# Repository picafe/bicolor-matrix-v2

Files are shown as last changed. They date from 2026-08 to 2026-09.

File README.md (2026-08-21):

# Bicolour Matrix

A 32x8 bicolor LED matrix module composed of 4 8x8 matrices based on the Holtek HT16K33A I2C LED driver. V1 paired it with a stacked adapter (RP2040 Zero + DS3231 module); V2 redesigns the matrix routing and puts an ESP32-C3, RTC, and environment sensors on a half-length adapter board behind the display.

V1 assembled clock showing the time

*V1 running as a clock*

## Inspiration

Inspired by the common 32x8 red LED matrix modules that use the MAX7219 IC, I wanted to make my own module but with more colours and functionality, while keeping the same asthetic.

I found [these](https://www.aliexpress.com/item/1005007029570407.html) modules while browsing Aliexpress and thought they could look be a cool alternative, costing ~$15 for 10 modules. With the red and light green variant, you can have red, a light green, and orange all in one module. As far as I'm aware, there aren't RGB modules in a similar form factor, although you can take generic WS2818 8x8 matricies and 3D print a diffuser for them, although the footprint is much bigger. This project was also partially inspired by [bitluni's LED magnet tiles](https://www.youtube.com/watch?v=L2J_eNgjxio) which I found really cool.

Unlike the single colour matricies with 16 pins, these had 24. I found [this](https://www.adafruit.com/product/902) Adafruit module and followed a similar schematic with the Holtek HT16K33A I2C LED driver.

For V2 I revisited the HT16K33A datasheet and realized any ROW/COL pin can map to any matrix row/column, thus routing got a lot simpler than matching Adafruit's pinout exactly.

## Structure

| Board | Role |
| --- | --- |
| **bicolour-matrix** | 32×8 display: 4× HT16K33A + 4× 8×8 bicolour matrices |
| **adapter-board-r2** | ESP32-C3-WROOM-02, CH340X USB-UART, YSN8900 RTC + CR2032, STCC4 (default CO₂; optional SCD41), SHT4x, BMP580, LIS2DW12 |
| **button-board-r2** *(optional / WIP)* | OLED + light sensor + touch pads |

The adapter is half the length of the matrix board and mates with a pin header between the middle modules so that the stack stays stable without a case.

The button board is a separate interface that is connected to the adapter board with a 7-pin JST SH connector. This is meant to be customized and built by the user themselves, although I've included a sample design with an OLED, light sensor, and 2x touch pads you can start from. What you include and how you integrate it is up to you and how you want to design an enclosure.

## Pictures

### Assembled (V1)

V1 boards laid out - adapter, button board, matrix

V1 side / stack view

### V2 

#### 3D

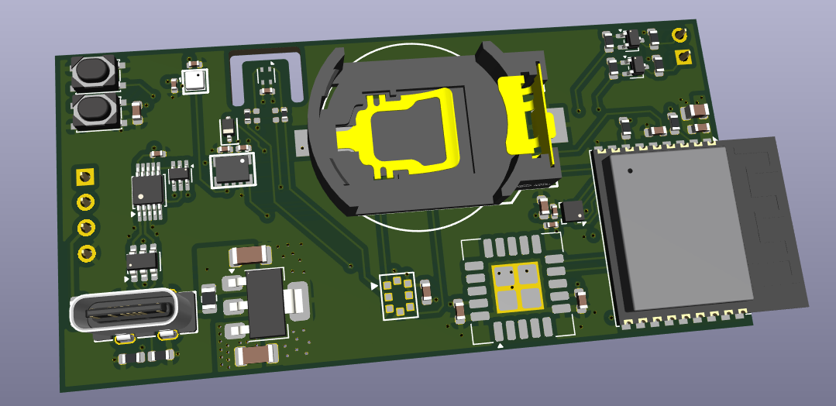
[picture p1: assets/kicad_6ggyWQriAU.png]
Adapter board R2 3D view


*Adapter board R2 (3D)*

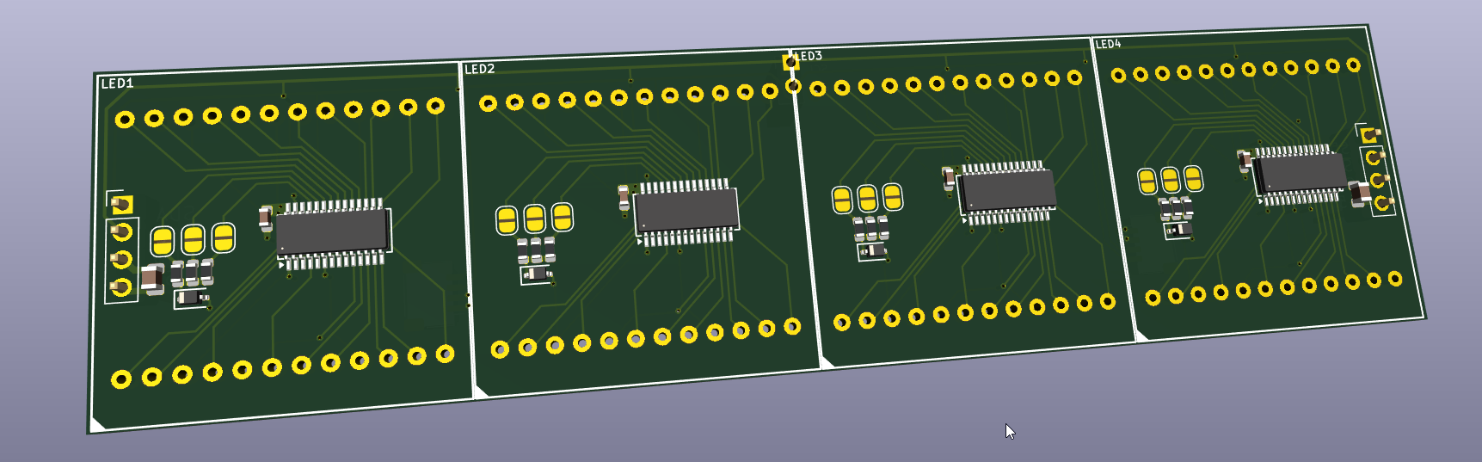
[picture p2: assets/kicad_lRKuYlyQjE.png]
Matrix board R2 3D view


*Matrix board R2 (3D)*

#### Schematics

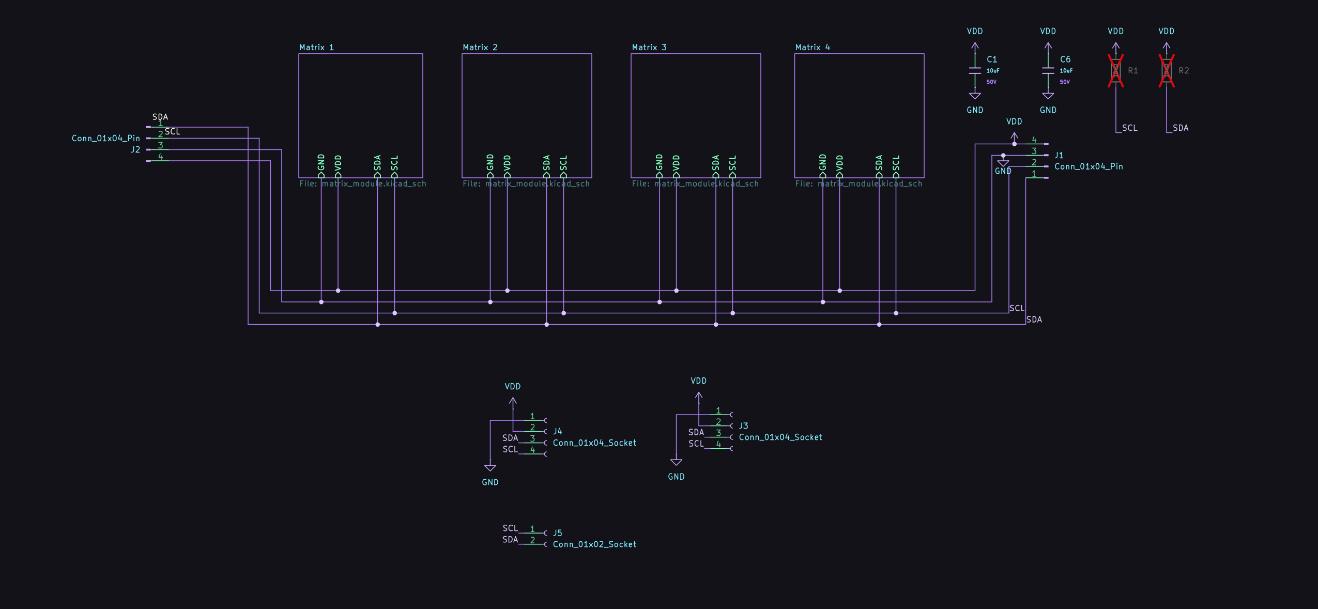
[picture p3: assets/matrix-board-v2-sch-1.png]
Matrix board schematic

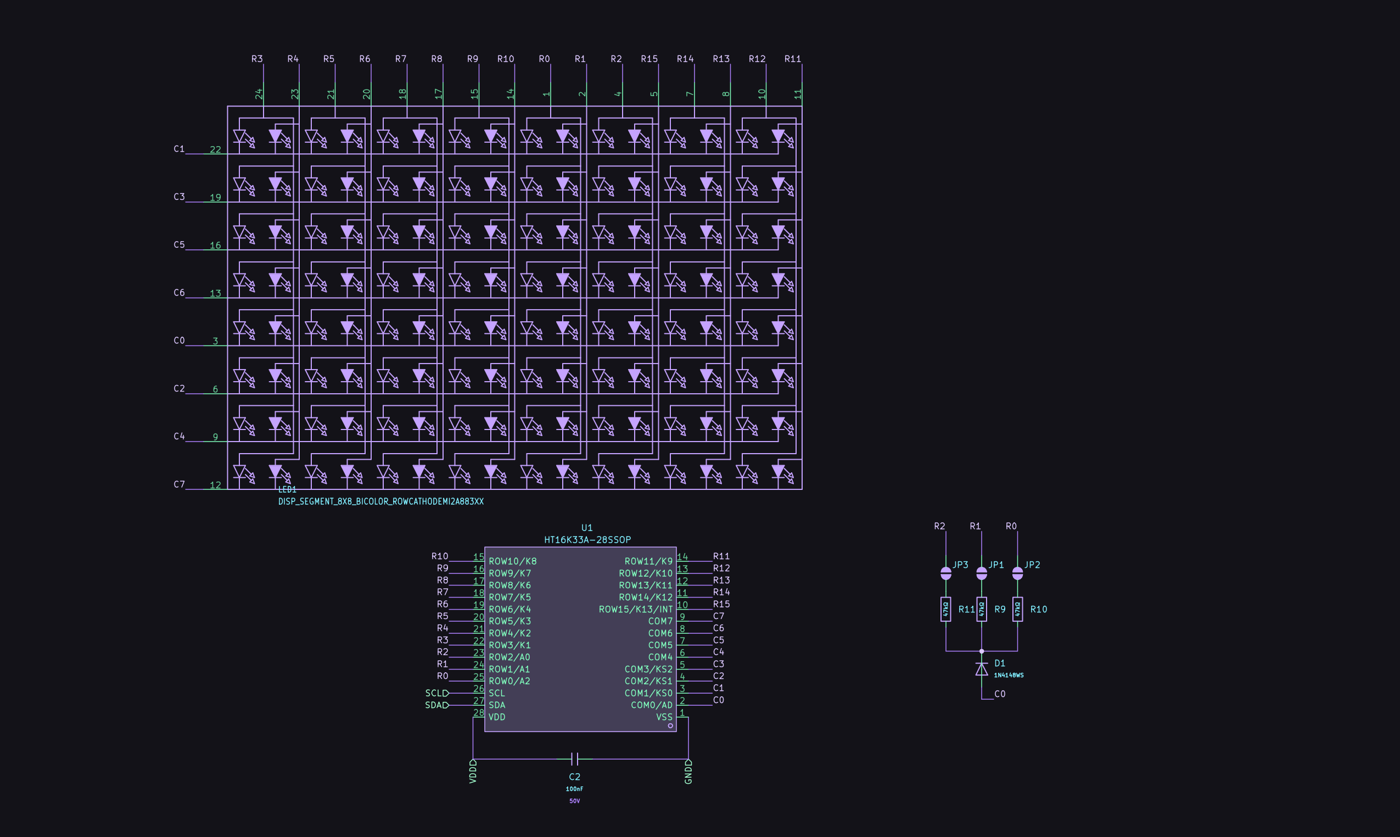
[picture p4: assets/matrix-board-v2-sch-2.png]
Matrix board module schematic


*Matrix board schematic*

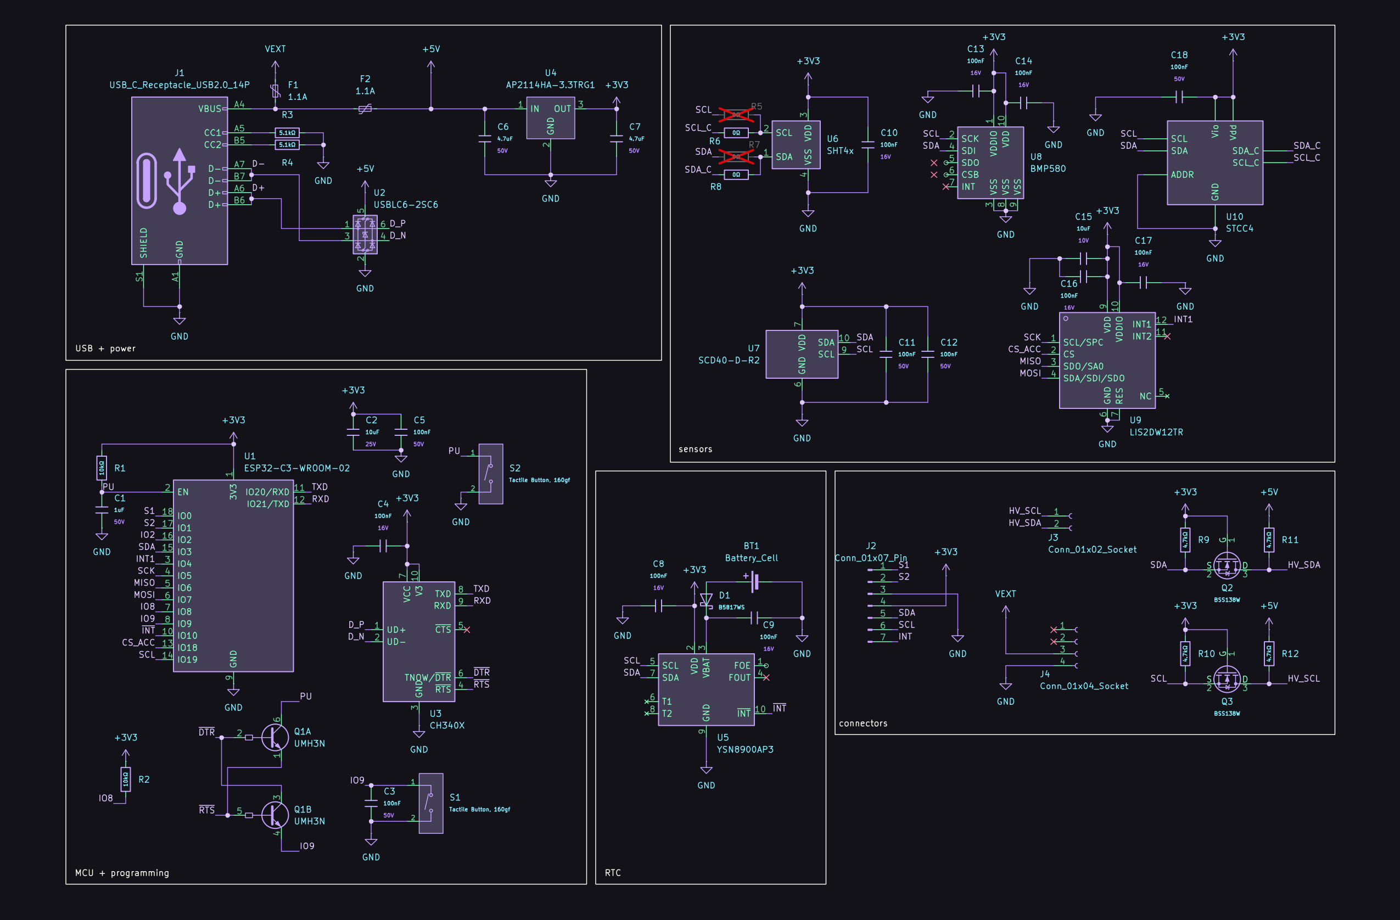
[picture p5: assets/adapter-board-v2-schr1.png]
Adapter board schematic

*Adapter board R2 schematic*

#### PCB

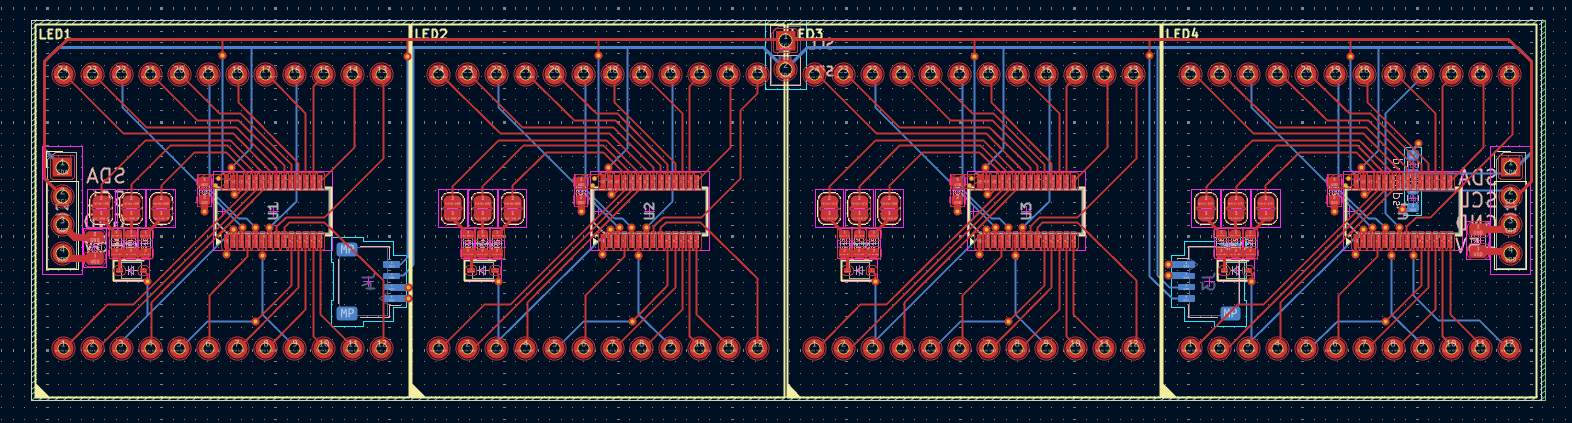
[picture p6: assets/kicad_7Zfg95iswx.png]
Matrix board R2 PCB layout


*Matrix board PCB (four HT16K33A modules)*

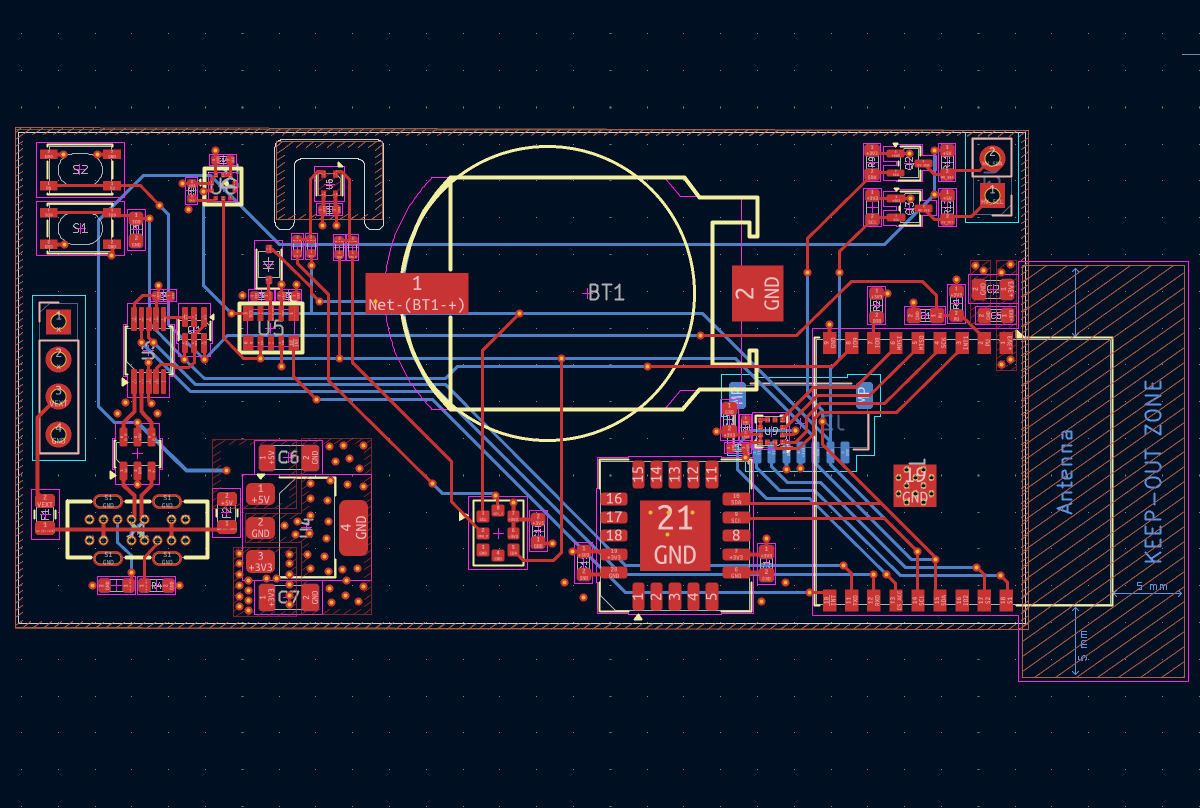
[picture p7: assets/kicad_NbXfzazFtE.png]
Adapter board R2 PCB layout


*Adapter board R2 PCB*

## Bill of materials

Prices are estimated from LCSC single-board quantities and AliExpress for the LED matrices.

### Matrix board (`bicolour-matrix`)

| Designator | Value | Footprint | Qty | LCSC | Unit cost (est.) | Line total (est.) |
| --- | --- | --- | --- | --- | --- | --- |
| C1, C6 | 10 µF | 0805 | 2 | C440198 | $0.02 | $0.04 |
| C2, C3, C4, C5 | 100 nF | 0603 | 4 | C14663 | $0.01 | $0.04 |
| D1, D2, D3, D4 | 1N4148WS | SOD-323 | 4 | C2128 | $0.01 | $0.04 |
| J1, J2 | 1×04 pin header | Through hole | 2 | — | $0.05 | $0.10 |
| J3, J4 | JST SH 1×04 (Qwiic-style) | SMD | 2 | — | $0.15 | $0.30 |
| J5 | 1×02 socket | Through hole | 1 | — | $0.05 | $0.05 |
| LED1, LED2, LED3, LED4 | 8×8 bicolour matrix | Module | 4 | AliExpress | $2.00 | $8.00 |
| R3, R4, R5, R9, R10, R11, R13, R14, R15, R18, R19, R20 | 47 kΩ | 0603 | 12 | C25819 | $0.002 | $0.02 |
| U1, U2, U3, U4 | HT16K33A | SSOP-28 | 4 | C5444738 | $0.54 | $2.16 |
| | | | | **Total (matrix, components only)** | | **~$10.75** |

### Adapter board (`adapter-board-r2`)

Default build uses the STCC4 for CO₂. An SCD41 (U7) can be fitted instead if R6/R8 are left open and the unpopulated R5/R7 0 Ω jumpers are fitted (routes the SHT4x onto the main I²C bus instead of the STCC4 compensation bus).

| Designator | Value | Footprint | Qty | LCSC | Unit cost (est.) | Line total (est.) |
| --- | --- | --- | --- | --- | --- | --- |
| BT1 | CR2032 holder | SMD | 1 | C7498149 | $0.15 | $0.15 |
| C1 | 1 µF | 0603 | 1 | C15849 | $0.01 | $0.01 |
| C3, C5, C11, C12, C18 | 100 nF | 0603 | 5 | C14663 | $0.01 | $0.05 |
| C4, C8, C9, C10, C13, C14, C16, C17 | 100 nF | 0402 | 8 | C1525 | $0.005 | $0.04 |
| C15 | 10 µF | 0603 | 1 | C19702 | $0.02 | $0.02 |
| C2 | 10 µF | 0805 | 1 | C15850 | $0.03 | $0.03 |
| C6, C7 | 4.7 µF | 1206 | 2 | C29823 | $0.03 | $0.06 |
| D1 | B5817WS | SOD-323 | 1 | C7420329 | $0.05 | $0.05 |
| F1, F2 | 1.1 A fuse | 0805 | 2 | — | $0.05 | $0.10 |
| J1 | USB-C receptacle 14P | Through hole | 1 | C3151746 | $0.30 | $0.30 |
| J2 | JST SH 1×07 | SMD | 1 | — | $0.25 | $0.25 |
| J3 | 1×02 socket | Through hole | 1 | — | $0.05 | $0.05 |
| J4 | 1×04 socket | Through hole | 1 | — | $0.08 | $0.08 |
| Q1 | UMH3N | SOT-363 | 1 | — | $0.08 | $0.08 |
| Q2, Q3 | BSS138W | SOT-323 | 2 | C28646265 | $0.03 | $0.06 |
| R1, R2 | 10 kΩ | 0603 | 2 | C25804 | $0.002 | $0.004 |
| R3, R4 | 5.1 kΩ | 0603 | 2 | C23186 | $0.002 | $0.004 |
| R6, R8 | 0 Ω (STCC4 / SHT4x compensation) | 0402 | 2 | C17168 | $0.004 | $0.008 |
| R9, R10, R11, R12 | 4.7 kΩ | 0603 | 4 | C23162 | $0.002 | $0.008 |
| S1, S2 | Tactile button, 160 gf | PTS810 | 2 | C720477 | $0.10 | $0.20 |
| U1 | ESP32-C3-WROOM-02 | Module | 1 | C2934560 | $3.13 | $3.13 |
| U2 | USBLC6-2SC6 | SOT-23-6 | 1 | C7519 | $0.18 | $0.18 |
| U3 | CH340X | MSOP-10 | 1 | C3035748 | $0.67 | $0.67 |
| U4 | AP2114HA-3.3TRG1 | SOT-223 | 1 | C460314 | $0.25 | $0.25 |
| U5 | YSN8900AP3 | SMD3225-10P | 1 | C54780223 | $1.46 | $1.46 |
| U6 | SHT4x | DFN-4 | 1 | — | $1.20 | $1.20 |
| U8 | BMP580 | LGA-10 | 1 | C22391138 | $0.96 | $0.96 |
| U9 | LIS2DW12TR | LGA-12 | 1 | C189624 | $1.26 | $1.26 |
| U10 | STCC4 | LGA | 1 | C49191471 | $10.06 | $10.06 |
| | | | | **Total (adapter, default build)** | | **~$20.73** |

Optional (not in default total): U7 SCD41 (~$18, C3659421) with R5/R7 fitted and R6/R8 open; leave U10 unpopulated.

**Combined components (matrix + adapter, default): ~$31.48**  
*(PCBs: ~$30 matrix + ~$12 adapter at JLCPCB)*

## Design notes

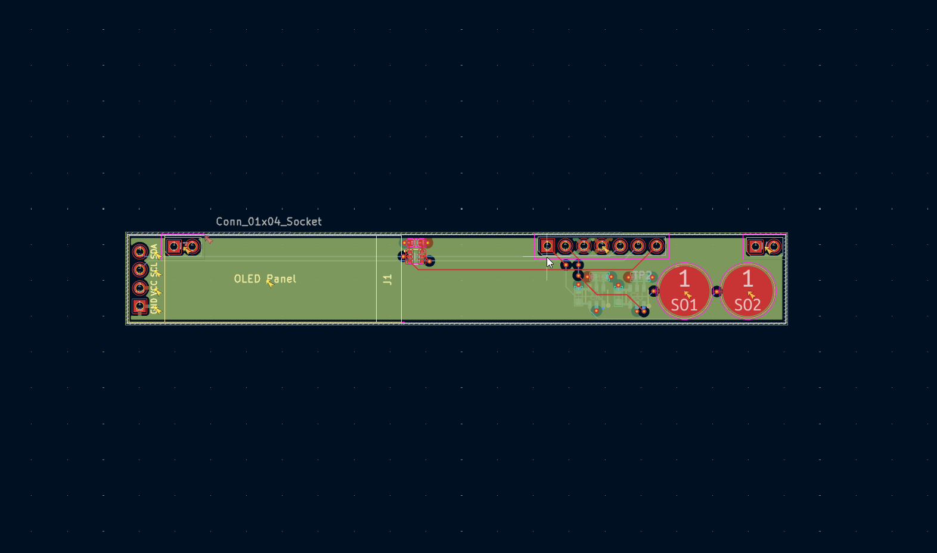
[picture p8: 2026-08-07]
assets/kicad_tJa7MA0nMc.png

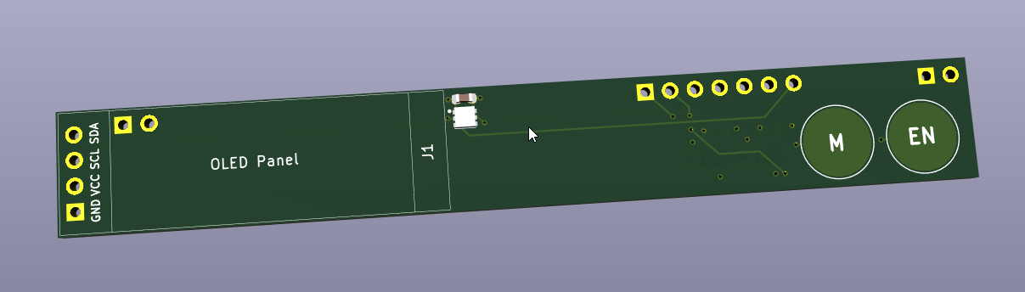
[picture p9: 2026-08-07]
assets/kicad_IC0JWIbxsM.png

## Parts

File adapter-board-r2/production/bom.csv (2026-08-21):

Designator | Footprint | Quantity | Value | LCSC Part #
BT1 | BAT-SMD_BS-CR2032-8 | 1 | Battery_Cell | C7498149
C1 | C_0603 | 1 | 1uF | C15849
C10, C13, C14, C16, C17, C4, C8, C9 | C_0402 | 8 | 100nF | C1525
C11, C12, C18, C3, C5 | C_0603 | 5 | 100nF | C14663
C15 | C_0603 | 1 | 10uF | C19702
C2 | C_0805 | 1 | 10uF | C15850
C6, C7 | C_1206 | 2 | 4.7uF | C29823
D1 | D_SOD-323 | 1 | B5817WS | C7420329
F1, F2 | 0805 | 2 | 1.1A
J1 | USB-C-TH_SHOUHAN_TYPE-C-14PLC-H10.0 | 1 | USB_C_Receptacle_USB2.0_14P | C3151746
J2 | JST_SH_SM07B-SRSS-TB_1x07-1MP_P1.00mm_Horizontal | 1 | Conn_01x07_Pin
J3 | PinSocket_1x02_P2.54mm_Vertical | 1 | Conn_01x02_Socket
J4 | PinSocket_1x04_P2.54mm_Vertical | 1 | Conn_01x04_Socket
Q1 | SOT-363_SC-70-6 | 1 | UMH3N
Q2, Q3 | SOT-323_SC-70 | 2 | BSS138W | C28646265
R1, R2 | R_0603 | 2 | 10kΩ | C25804
R10, R11, R12, R9 | R_0603 | 4 | 4.7kΩ | C23162
R3, R4 | R_0603 | 2 | 5.1kΩ | C23186
R6, R8 | R_0402 | 2 | 0Ω | C17168
S1, S2 | SW_SPST_PTS810 | 2 | Tactile Button, 160gf | C720477
U1 | ESP32-C3-WROOM-02 | 1 | ESP32-C3-WROOM-02
U10 | STCC4 | 1 | STCC4 | C49191471
U2 | SOT-23-6 | 1 | USBLC6-2SC6
U3 | MSOP-10_3x3mm_P0.5mm | 1 | CH340X
U4 | SOT-223 | 1 | AP2114HA-3.3TRG1 | C460314
U5 | OSC-SMD_10P-L3.2-W2.5-BL_RX8130CE | 1 | YSN8900AP3 | C54780223
U6 | Sensirion_DFN-4_1.5x1.5mm_P0.8mm_SHT4x_NoCentralPad | 1 | SHT4x
U7 | Sensirion_SCD4x-1EP_10.1x10.1mm_P1.25mm_EP4.8x4.8mm | 1 | SCD40-D-R2
U8 | LGA-10_L2.0-W2.0-P0.50-TL_BMP580 | 1 | BMP580 | C22391138
U9 | LGA-12_2x2mm_P0.5mm | 1 | LIS2DW12TR | C189624

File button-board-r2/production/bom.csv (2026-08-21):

Designator | Footprint | Quantity | Value | LCSC Part #
C1, C3, C5 | C_0603 | 3 | 100nF | C14663
C2, C4 | C_0603 | 2 | 22pF | C1653
J1 | SSD1306-0.91-OLED-4pin-128x32 | 1 | Conn_01x04_Socket
J2 | JST_SH_SM07B-SRSS-TB_1x07-1MP_P1.00mm_Horizontal | 1 | Conn_01x07_Pin
TP1, TP2 | TestPoint_Pad_D4.0mm | 2 | TestPoint
U1 | SENSORS-SMD_VEML6030 | 1 | VEML6030 | C132182
U2, U3 | SOT-23-6_L2.9-W1.6-P0.95-LS2.9-BL | 2 | TTP223-BA6-TD | C42422127

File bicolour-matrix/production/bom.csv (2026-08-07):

Designator | Footprint | Quantity | Value | LCSC Part #
C1, C6 | C_0805 | 2 | 10uF | C440198
C2, C3, C4, C5 | C_0603 | 4 | 100nF | C14663
D1, D2, D3, D4 | D_SOD-323 | 4 | 1N4148WS | C2128
J1, J2 | PinHeader_1x04_P2.54mm_Vertical | 2 | Conn_01x04_Pin
J3, J4 | JST_SH_SM04B-SRSS-TB_1x04-1MP_P1.00mm_Horizontal | 2 | Conn_01x04_Socket
J5 | PinSocket_1x02_P2.54mm_Vertical | 1 | Conn_01x02_Socket
LED1, LED2, LED3, LED4 | SEGMENT_BICOL_BL-M12A883XX | 4 | DISP_SEGMENT_8X8_BICOLOR_ROWCATHODEMI2A883XX
R10, R11, R13, R14, R15, R18, R19, R20, R3, R4, R5, R9 | R_0603 | 12 | 47kΩ | C25819
U1, U2, U3, U4 | SSOP-28_3.9x9.9mm_P0.635mm | 4 | HT16K33A-28SSOP | C5444738

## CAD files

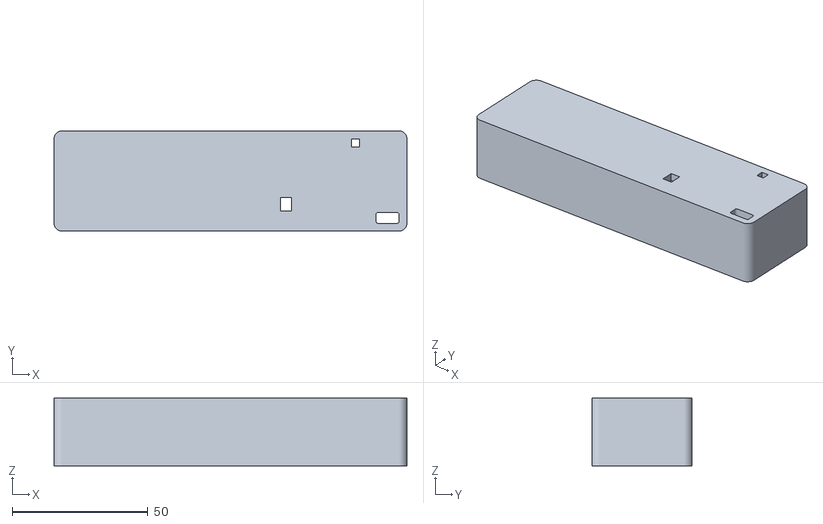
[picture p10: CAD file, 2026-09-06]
cad/Enclosure-r2.stl
130.0 x 37.0 x 25.0

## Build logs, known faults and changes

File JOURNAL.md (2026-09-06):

Total time spent: 21 hours

# June 15, 2025: Coming back for R2 - freer pinout & QWIIC

Note: I built R1 over the span of a few months, modifying a few things as I went. I didn't record many details, but the finished results are pictured in the README.md.

I wanted to come back to this project as I realized a few days earlier while revisiting the HT16K33A datasheet that I didn't realize before (since I wasn't too proficient in reading datasheets; in fact I doubt I even read it in detail back then). In my original design, I decided to follow the exact connections Adafruit used in their module, not realizing that any ROW pin on the HT16K33A can be connected to any row on the display matrix and such with COL pins too. This meant that I could simplify the routing a lot. I also wanted to include QWIIC connectors to make it easy to chain 2 modules together (the max that can be connected on the same bus, since I2C addr select is 3 bits/jumpers).

I tested the setup on a breadboard and asked Claude to make a modification to the library implementation for the new pinout, which worked fine. I also wanted to change the adapter board to include an actual microcontroller itself rather than a soldered module. The current solution is not too neat/ideal. I'm thinking maybe a NRF52840/NRF52833 module.

I started (and finished) work on the matrix module itself pretty easily. It took a bit to remember how to use the replicate layout plugin again and route the rest manually.

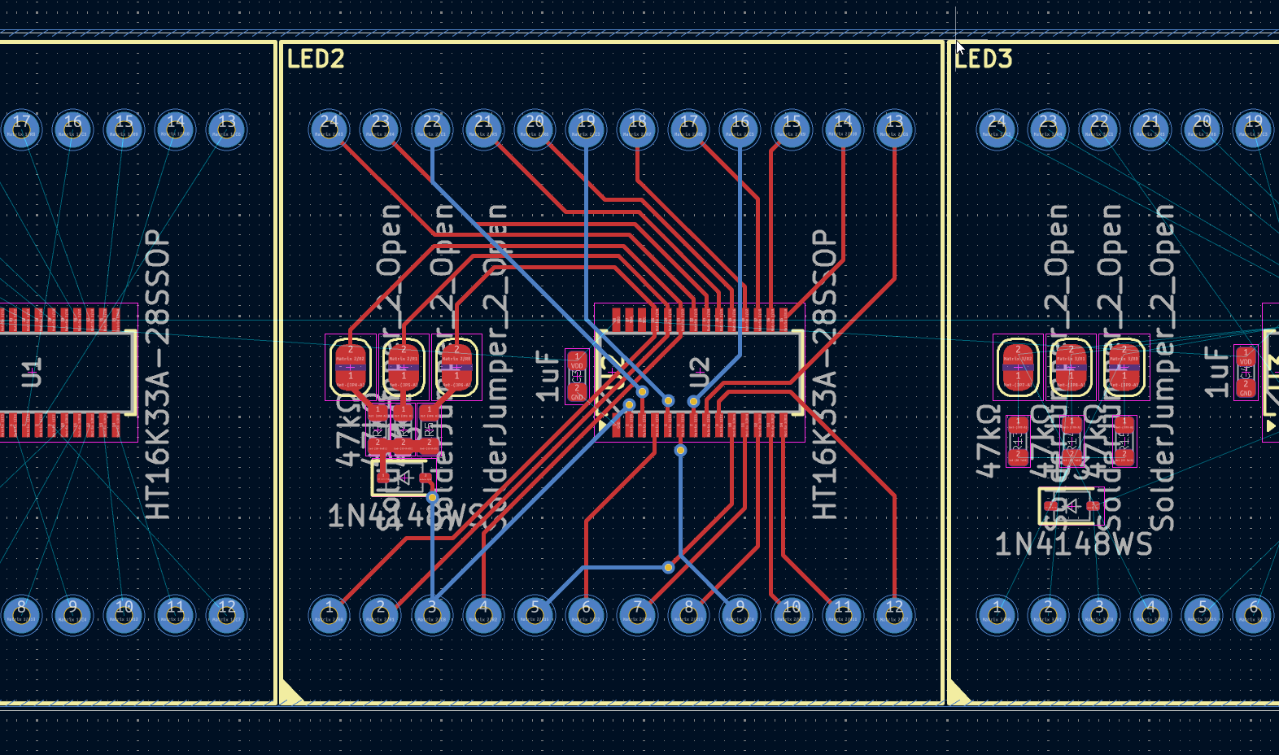
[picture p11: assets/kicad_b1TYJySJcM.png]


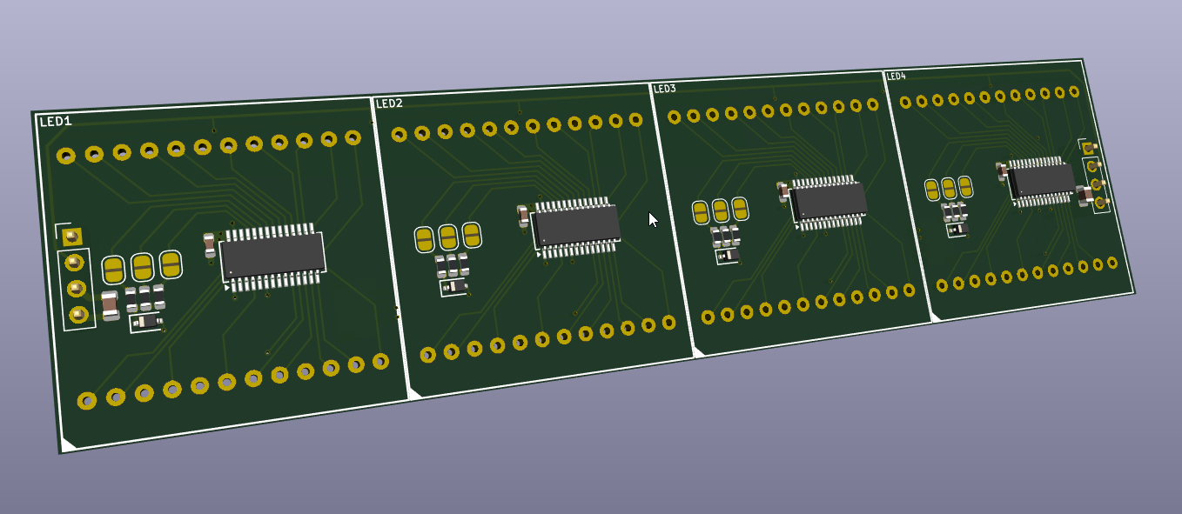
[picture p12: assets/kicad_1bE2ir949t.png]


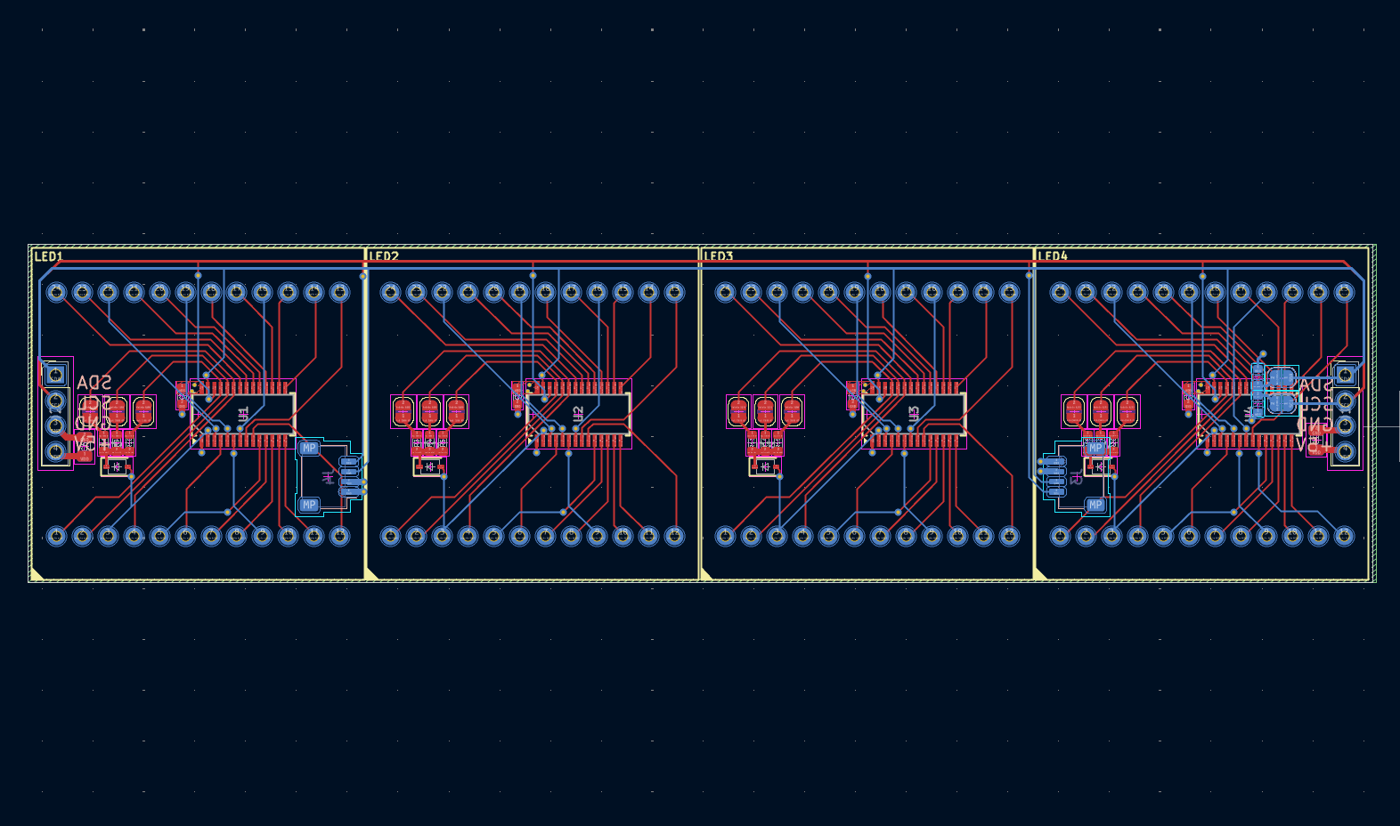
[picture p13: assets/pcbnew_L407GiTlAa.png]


**Total time spent: 3 hours**

# July 9, 2026: Started adapter board - switched to ESP32-C3

I have been a bit busy and procrastinating taking on the main task of making the adapter board. But I have finally started working on it. I decided to go with the ESP32-C3 WROOM module since it's small, has enough GPIO and is fairly cheap. The main reason I switched from what was initially planned (despite actually importing the symbol and starting the schematic) was that I wanted to make the programming/setup easy through something like a web dashboard which I would make a PWA. Would be much simpler than using Zephyr or Arduino IDE with Nordic MCU. ESP ecosystem w/ Arduino also has more overall support. It is also slightly cheaper than the NRF52840/NRF52833 module from Ebyte I planned on using.

I spent a while reading over the ESP32-C3 WROOM datasheet, integration guide, placement requirements and took a lot at the schematic + PCB for the devboard. I also read up on the boot and reset behaviour, and figured it would just be easier to use a CH340 instead of onboard USB for programming, since it supports autoreset.

Since board space isn't an issue, I went for CH340N. It took me a while to find an appropriate LDO for the system, since my system probably would have current peaks of 500mA+. I wanted to use a SOT-23 package since it's easy to route and after scrolling past the pages of 1117-style regulators, I found the AP2114HA, which is suitable. After drafting a quick schematic, I called it for the day. But before that, I cleaned up the schematic a bit.

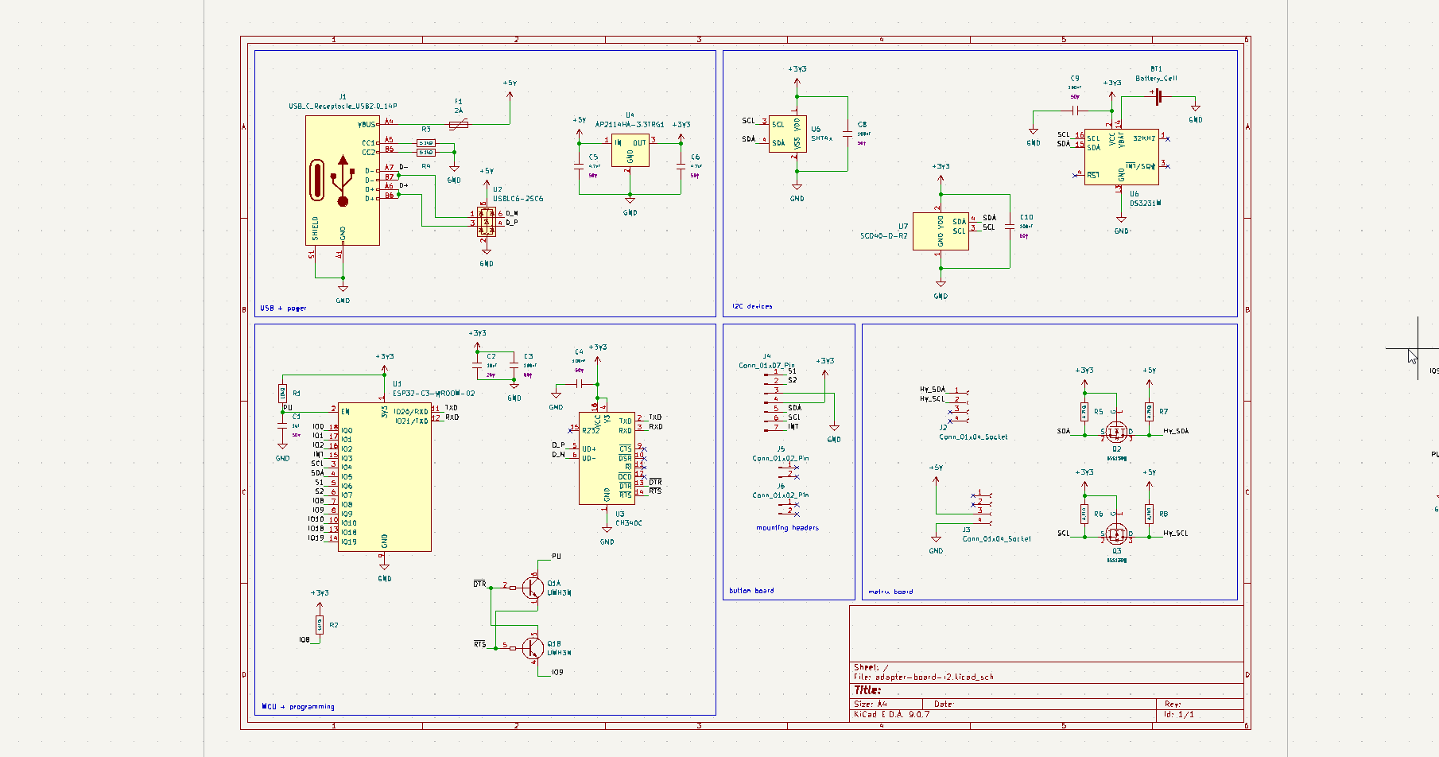
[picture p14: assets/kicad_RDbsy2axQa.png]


**Total time spent: 3.5 hours**

# July 10, 2026: Routed the adapter board - then sticker shock at JLC

I finally locked in an routed the majority of the adapter board, although I still had quite a bit of empty space on the board; it felt like a lot of space being wasted. The routing was fairly simple and took me in total about 2.5 hours becuase of the low component density. The main things were connecting the D+/D- pairs together on the horizontal USB connector since they crossed each other in a somewhat X shape and I needed 5V to pass through the middle of the connector. Eventually, I just resorted to using the inner GND layer to connect them as there wasn't a filled region in that area due to keepout.

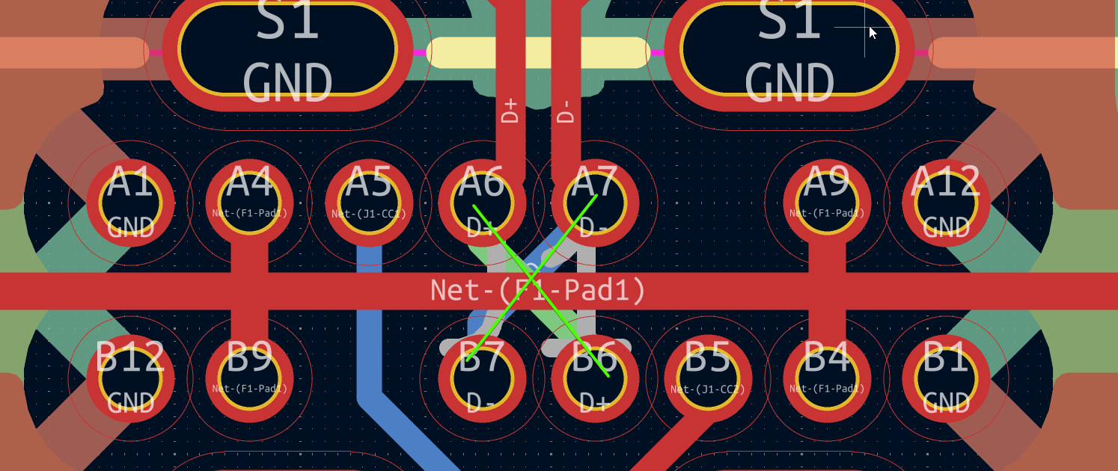
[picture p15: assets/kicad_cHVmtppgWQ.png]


After I while I was done routing:

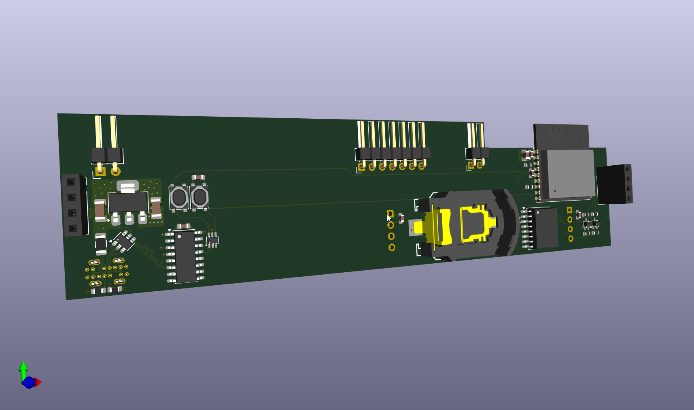
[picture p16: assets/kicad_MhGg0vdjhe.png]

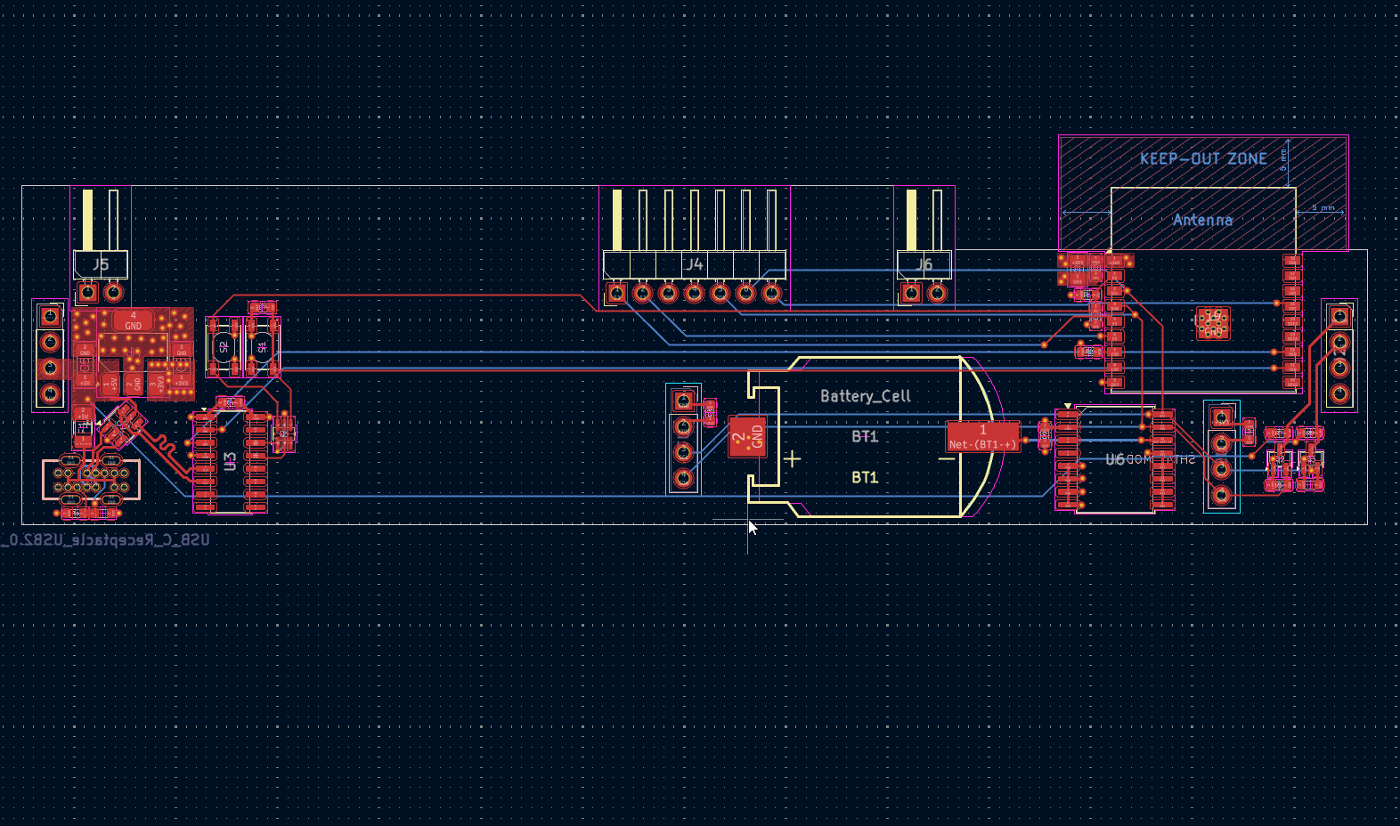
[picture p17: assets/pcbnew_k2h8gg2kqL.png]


However, when I was done routing, I put the PCB into JLC to see how much it would cost, since I've never ordered a 4 layer board above 100x100mm. It turned out to be quite expensive...

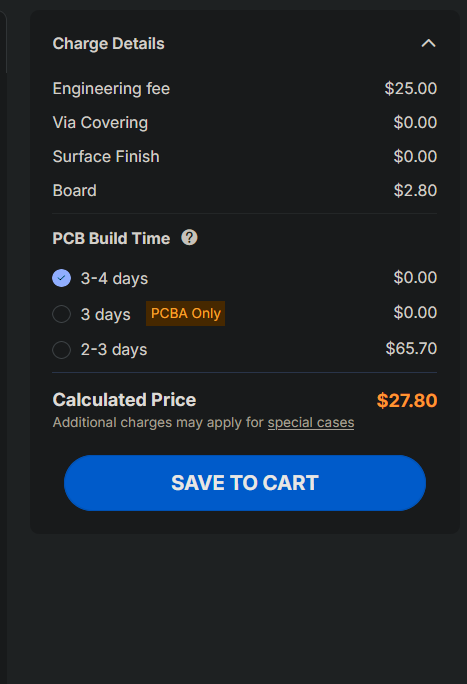
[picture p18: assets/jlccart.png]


I figured this would be acceptable for the matrix board since essentially all of the space was utilized, however since the adapter board is pretty bare, I figured it would likely be better to split this into 2 boards potentially, or make the board smaller and attach it to the matrix board with an additional pin header in the middle between one of the modules.

First I tried to see what it would look like to split the board into 2, with a pin header in the middle between the two modules. Even with this setup, the board would be pretty empty and there would be quite a bit of space wasted.

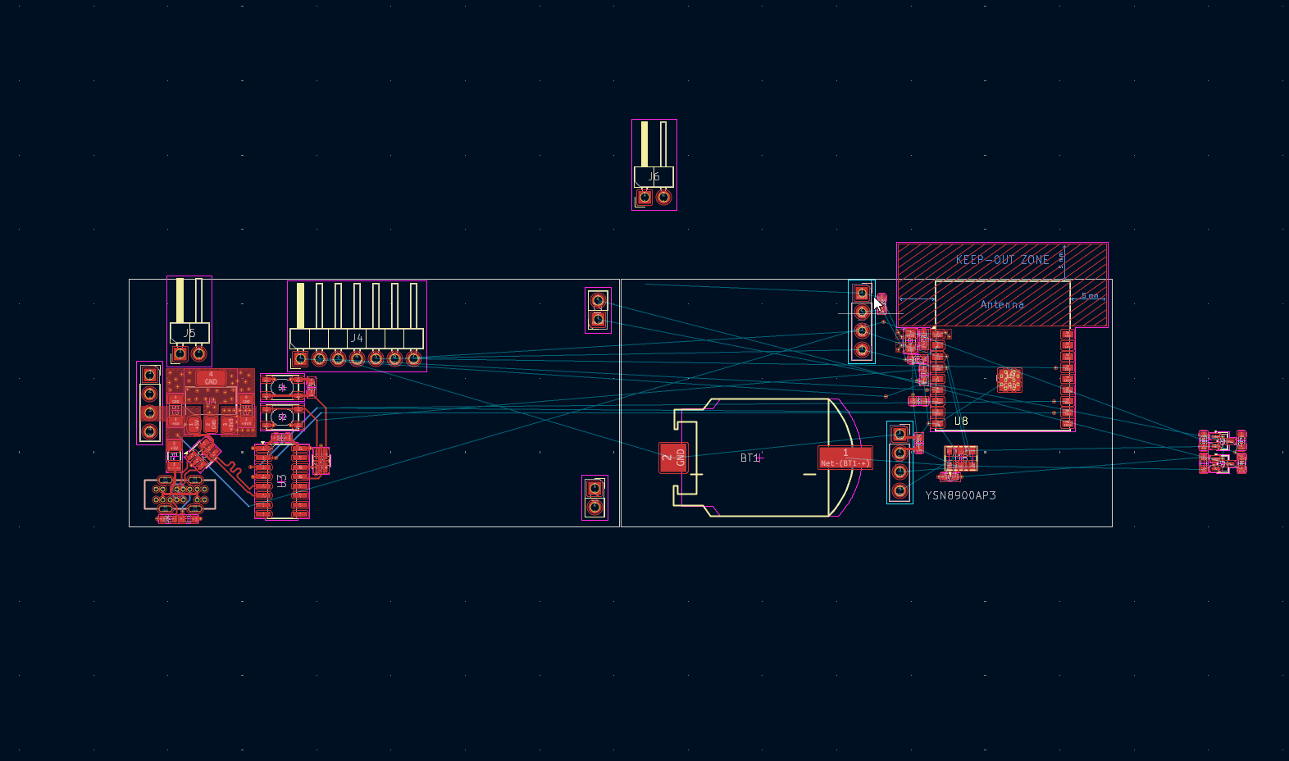
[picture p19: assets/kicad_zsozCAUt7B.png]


The distance betweenm the first and 3rd module is essentially 100mm, so this is essentially the maximum distance that could be supported by a single board.



I thought initially this would be a good idea, since it would mean more space for routing and maximizing the PCB per cost that I pay for, but when I tried the rough layout, it was pretty hard to fit something in exactly 100mm without having the pin header holes on the matrix board being in a weird position or without having the pin header keepout be off the edge of the adapter board:

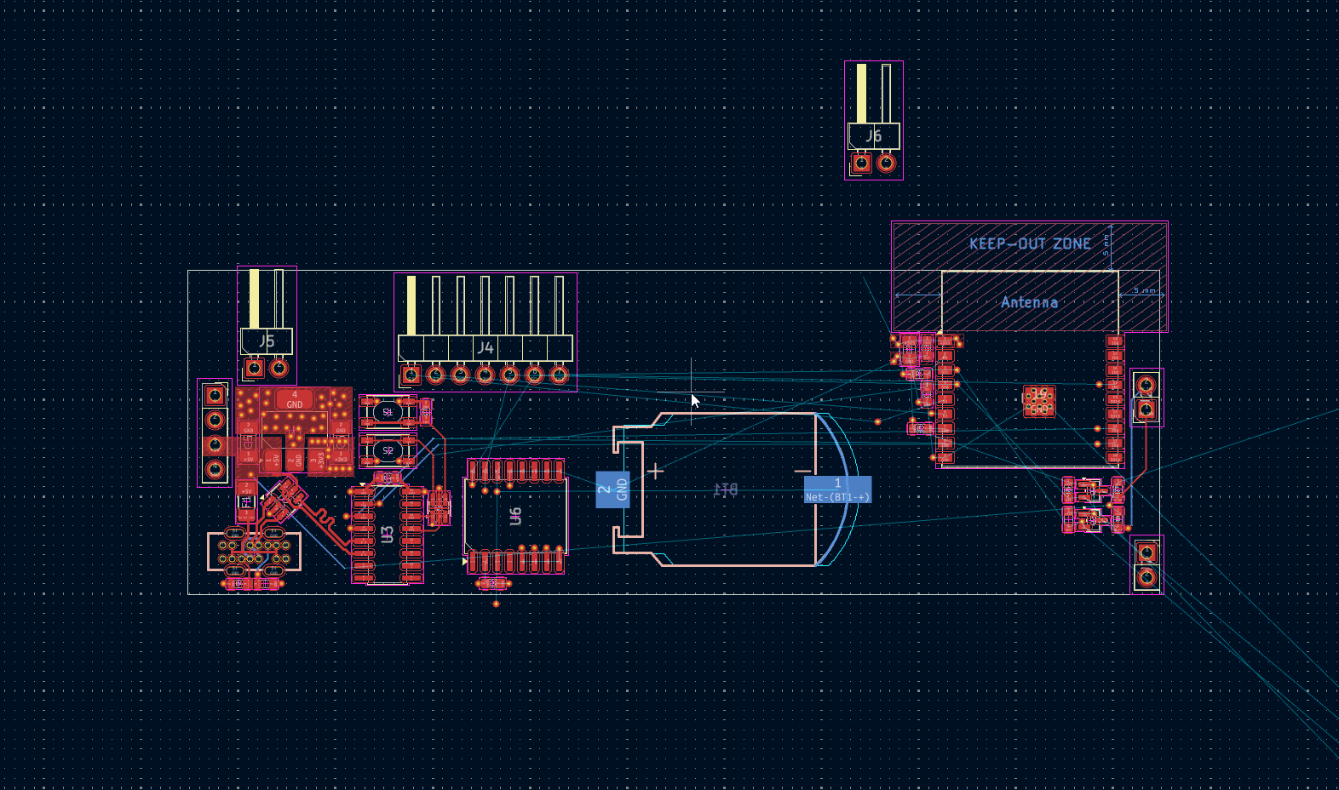
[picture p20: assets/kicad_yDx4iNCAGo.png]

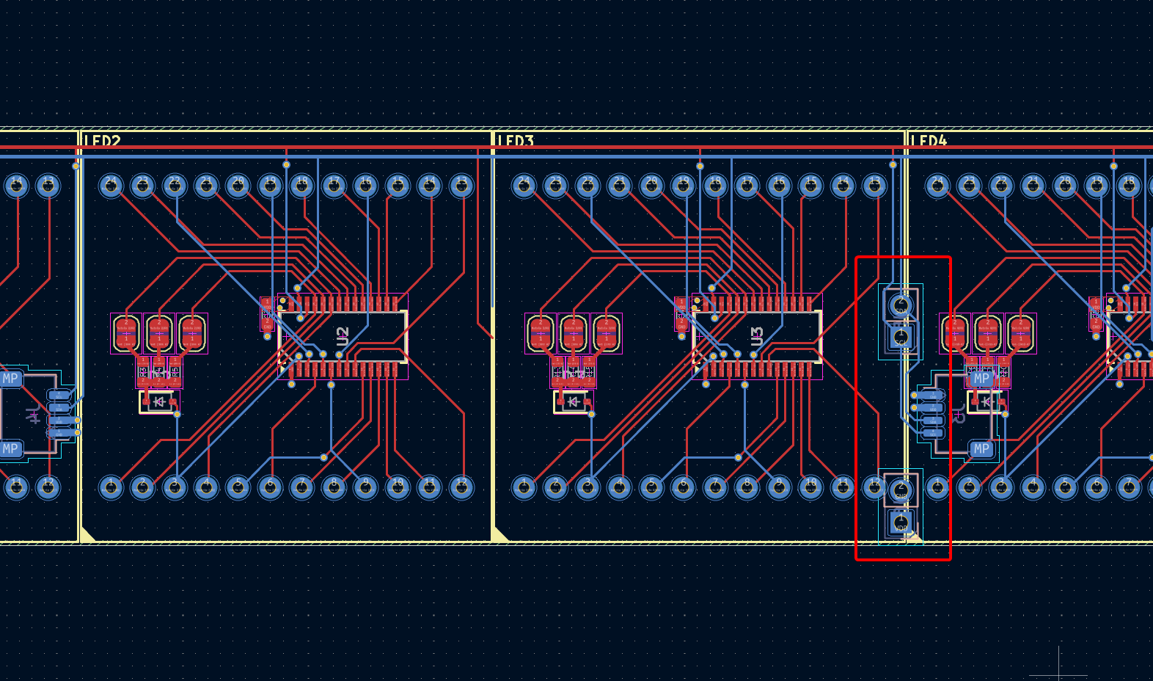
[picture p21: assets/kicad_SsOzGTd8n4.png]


Therefore, I settled on having the adapter board be half the length of the matrix module, and then having a pin header in the middle between the two modules.

**Total time spent: 6 hours**

# July 12, 2026: Rethinking layout - sensors go on the board

Before pretty much starting again on the adapter board, I decided to rethink a bit of the layout.
After reading the ESP32-C3 WROOM datasheet/recommand layout position documentation again, I decided on this new setup:

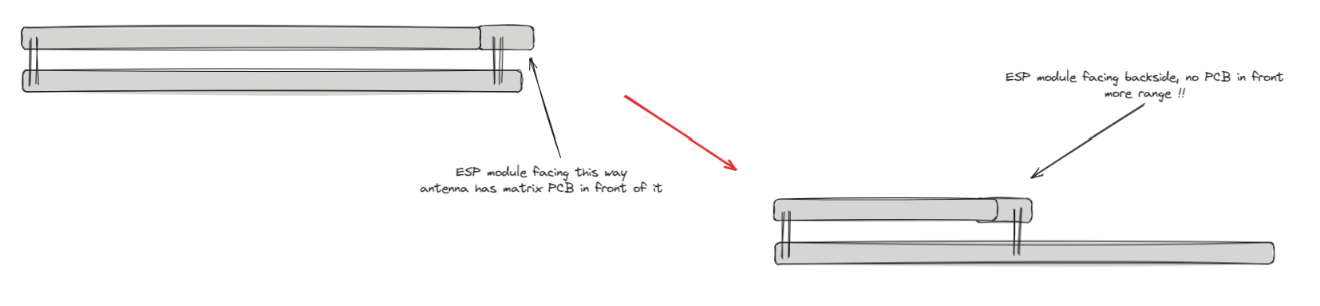
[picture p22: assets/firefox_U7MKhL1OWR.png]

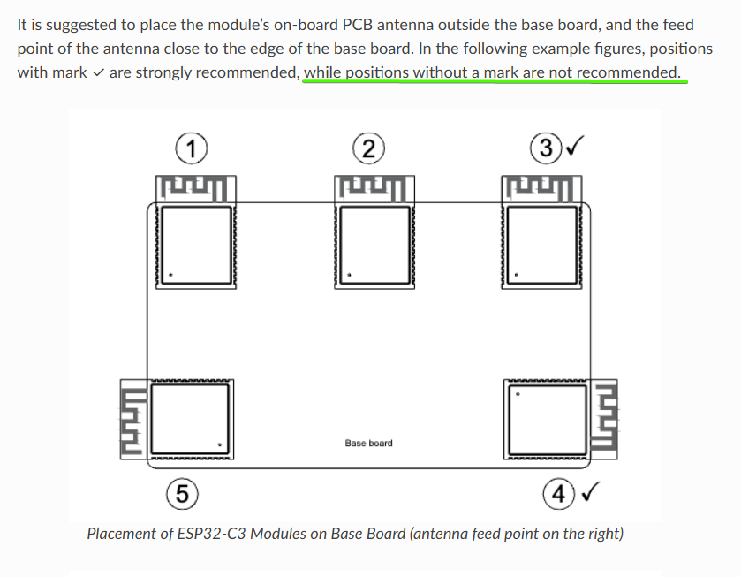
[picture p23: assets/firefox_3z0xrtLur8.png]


Since my previous layout had the module on the top side, I thought it might be better to place it sideways on the bottom now to accomadate more space for the pins to connect to the matrix board. Previously, I was also planning on using SCD41 and SHT41 breakout boards since they would be easy to solder, but I eventually decided to just use the actual sensors themselves and work on getting a better SMT setup, since I plan to assemble the board myself. Since everything was also going on the backside, I could include all the sensors on the same side since the SCD40 is about the same height as the vertical USB connector, which are both the tallest items on the board. I could also make an enclosure that follows one of the recommended layouts for general environment sensors to have them inside an isolated cavity in the case which is openly exposed, such that heat from components inside would not affect the sensors. Something like this:

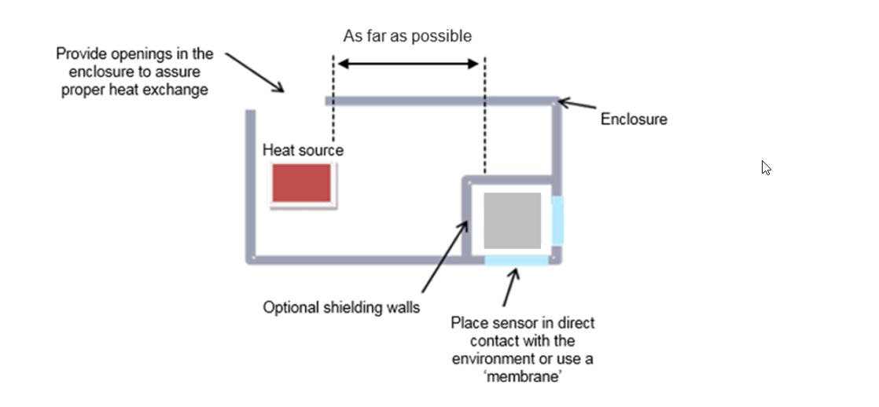
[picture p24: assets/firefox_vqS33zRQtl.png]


However, for now the design is intended to be caseless; which is one of the reasons why I spent so long trying to find a layout that works since pin headers need to be mounted on both sides of the board for it to be stable. I did previously work on a revision 2 of the button board which includes an 128x32 OLED, light sensor and 2 touch pads, it'll likely be redesigned later on so that I can figure out a better way to mount it to everything else with or without a case. I like the raw matrix/electronic look of the board, which is a reason why I want to keep this compatible without a case. This is still something I'm debating since environment sensors aren't too good with dust and such, but I think I'll probably make a version with a case later on.

After reading the SCD4x datasheet, I realized that the sensor has temperature and pressure compensation for CO2 concentration, so a better temperature/humidity sensor and a pressure sensor would be ideal for better accuracy. Out of the options on LCSC, I picked the ENS210 since it has the best specs based on what was available for a reasonable unit price. The SCD41 isn't available on LCSC, but I figured its big enough to order a module and desolder it, which would not be a good idea for the SHT41 since it's quite tiny. For pressure, I went with the BMP580; new and accurate. Although board heating shouldn't have much of an effect on the BMP580, I tried to keep it separate but not on an island by itself like I planned to do with the ENS210.

**Total time spent: 2 hours**

# July 16, 2026: Finished adapter board - sensors, RTC, accelerometer

After returning from a brief break, I decided to start working on the adapter board again. I decided to go with the same layout as I planned before (half the length of the matrix module), but with the new sensors and some other changes. One thing I did though was switch to the CH340X since it's smaller and I needed the extra space. Oh yeah, I also decided to go with a different RTC other than the DS3231 since it's fairly hard to source them nowadays and they're in a fairly big package. I went with a clone of the Epson RX8900SA from YXC (YSN8900AP3), which is a drop-in replacement from a trusted brand. It has an integrated TCXO in a SMD3225-10P package, making it easy to hand solder (with a reflow plate), small, accurate, and much cheaper than the DS3231.

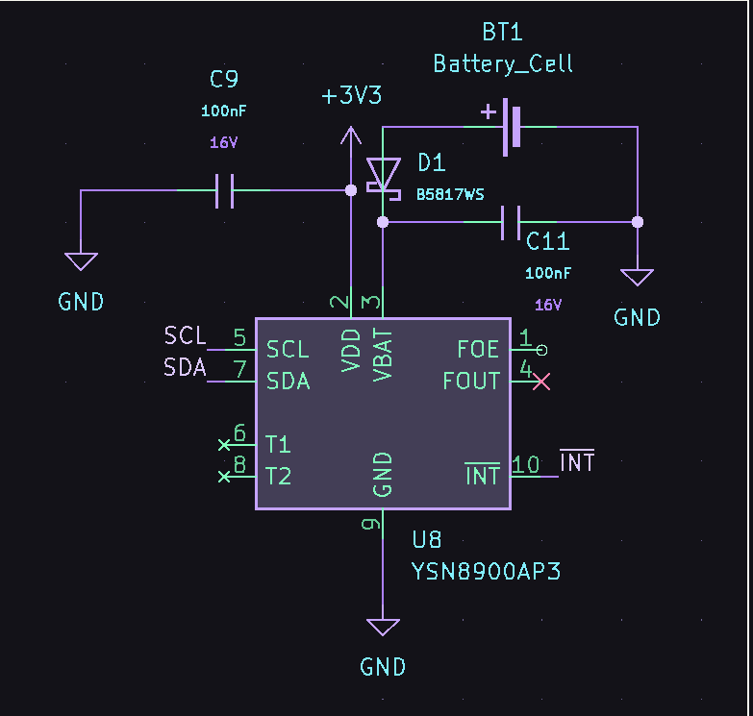
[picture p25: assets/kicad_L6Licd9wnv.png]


Routing in progress:

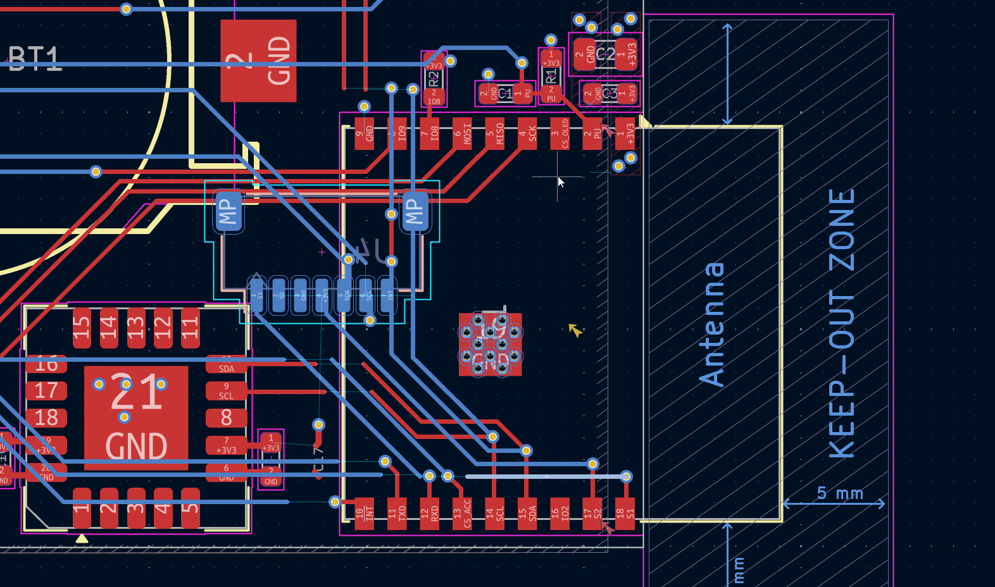
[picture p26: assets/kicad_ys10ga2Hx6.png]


Although it took quite a bit to route and get everything ironed out, finally managed to get something I considered acceptable. It was a bit hard to route the battery holder since I had to account for the battery radius (which was not included in the footprint), but overall it was not too bad.

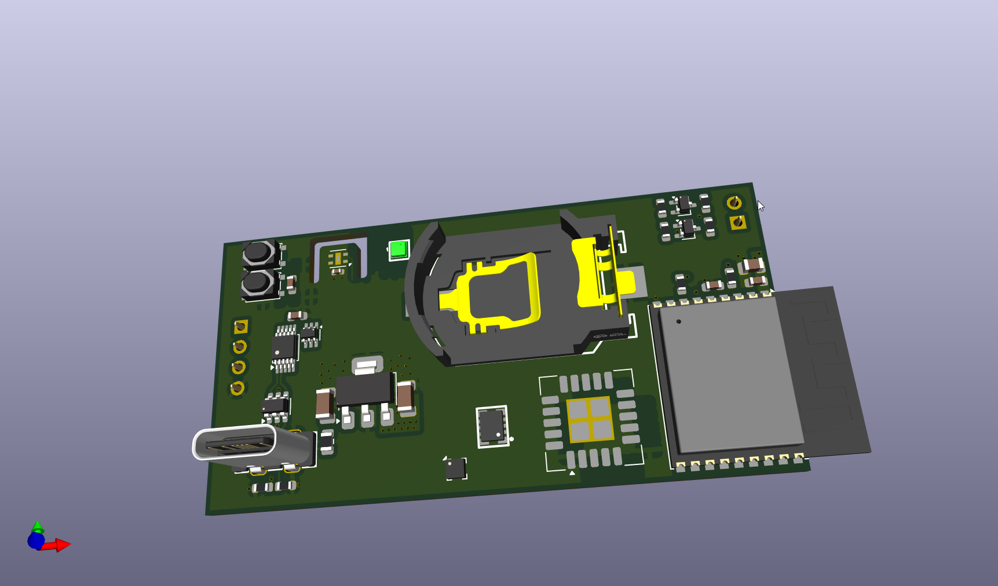
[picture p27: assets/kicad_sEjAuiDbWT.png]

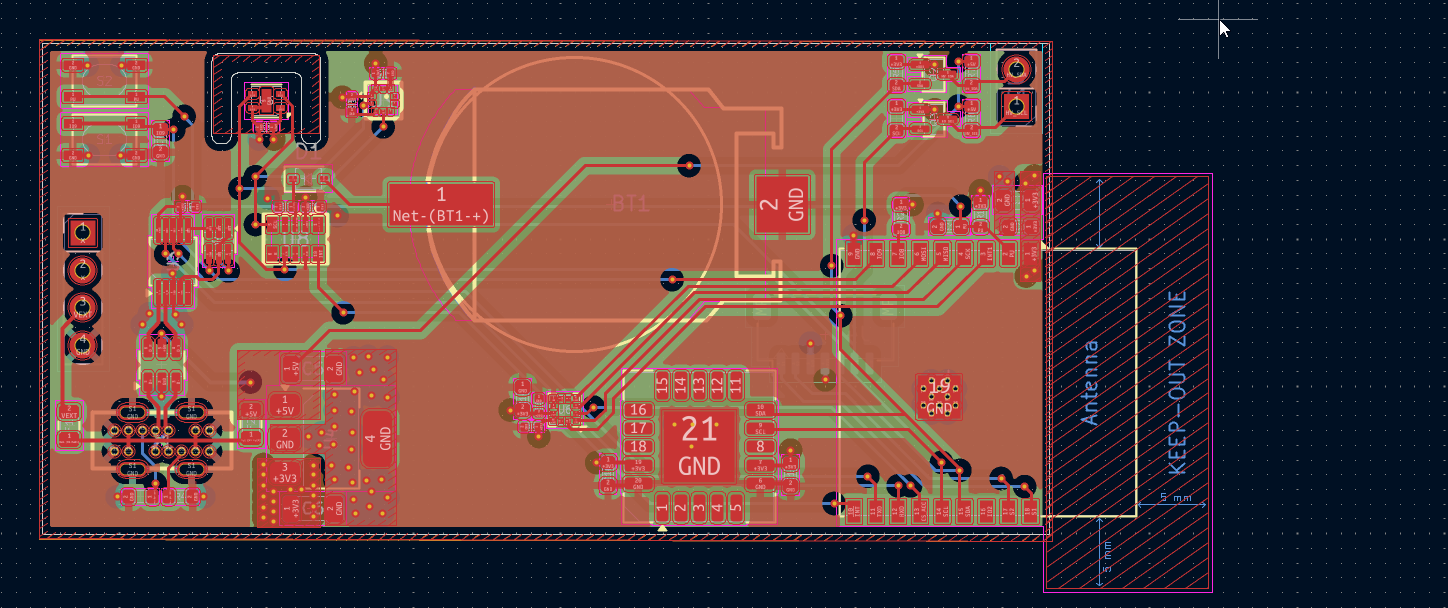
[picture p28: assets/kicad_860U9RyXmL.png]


Somewhere along the way, I also decided to add an accelerometer (LIS2DW12) to make this cable of some particle motion simulation or something like an hourglass feature, which would be pretty cool especially with 3 crisp colours on the matrix displays. After exporting the BOM and PCB to LCSC and JLC, everything came out to roughly $12 for the adapter board PCB, $35 for parts, and $30 for the matrix board PCB.

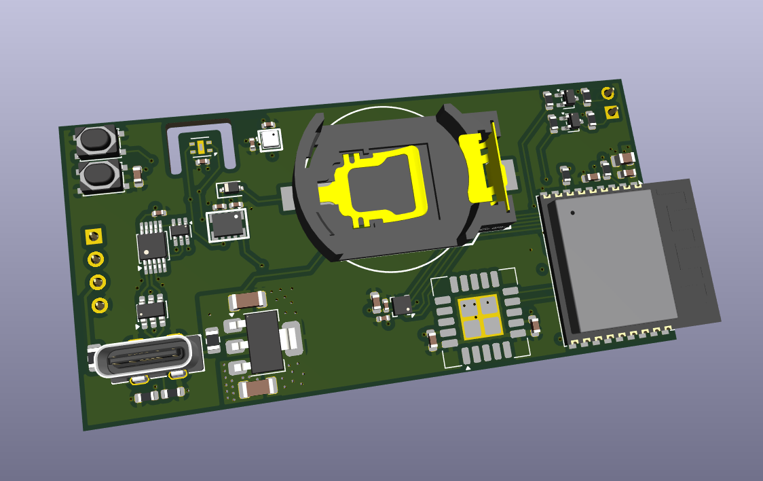
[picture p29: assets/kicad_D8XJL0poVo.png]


**Total time spent: 4 hours**

# August 18, 2026: Changed components - STCC4, SHT4x

After doing some cost comparisons, I decided to go with the STCC4 for CO₂ instead of the SCD41 while also keeping pads for the SCD41 in case. I also decided to go with the SHT4x for humidity and temperature instead of the ENS210, since it's supported by default with the STCC4 for compensation. I just added 0402 0 ohm jumpers to connect the SHT4x to the STCC4 compensation bus instead of the main I²C bus. I also had to re-route a lot of other components like the accelerometer and RTC to fit traces.

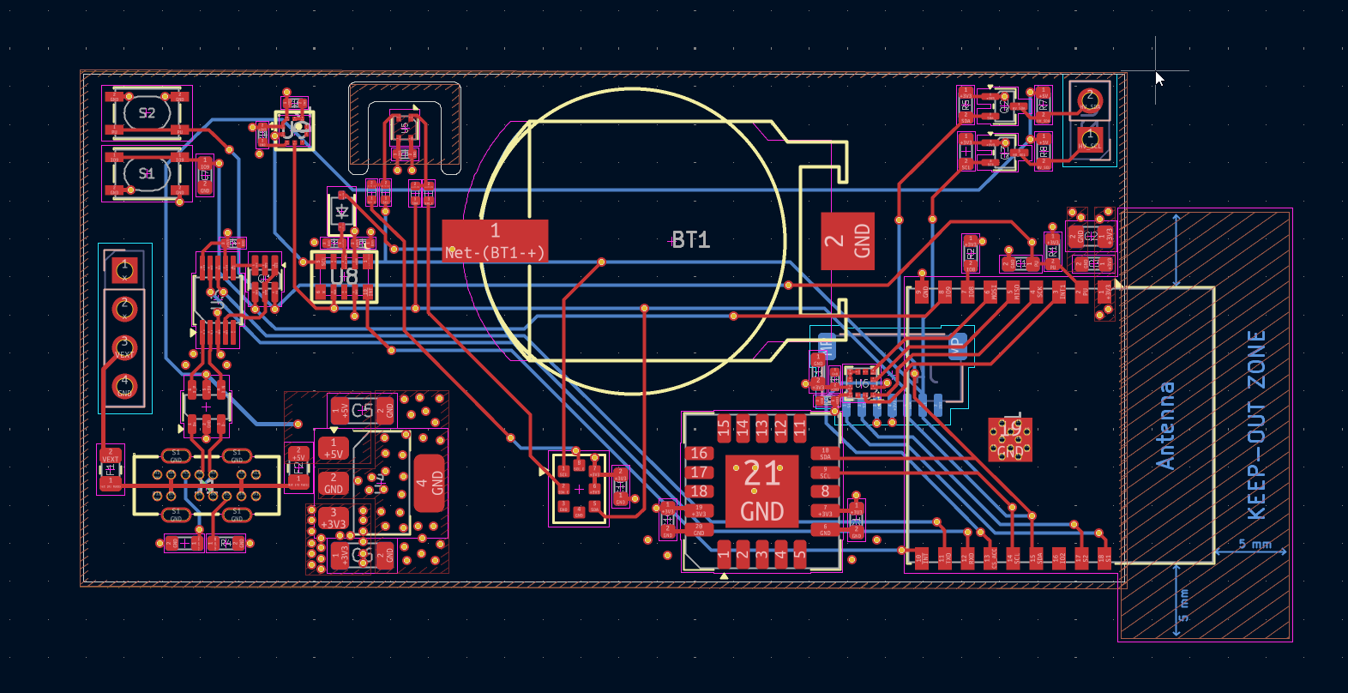
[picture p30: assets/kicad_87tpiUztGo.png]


**Total time spent: 1.5 hours**

# August 26, 2026: Routing and silkscreen changes

I made a few changes to the routing of the main adapter board, since I had some traces in weird places from before; since I had to move matricies to adjust alignment so a few traces were not perfectly straight. Since I have to get this via a green PCB, the misalignment would be noticeable. I also added some orph and heidi pcb art from hc stickers!! I also added silkscreen labels for everything.

**Total time spent: 1 hour**

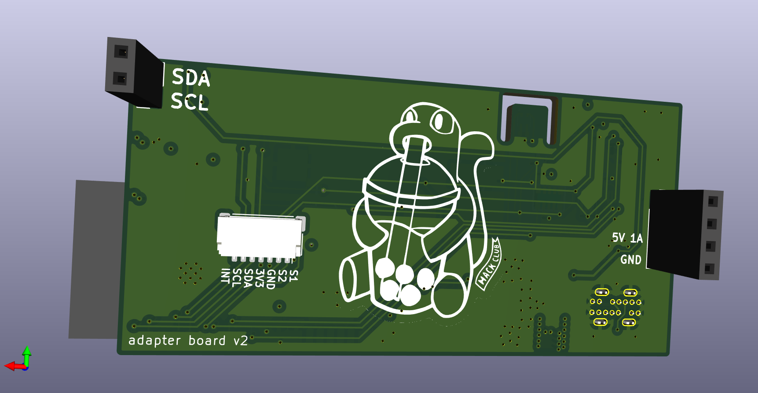
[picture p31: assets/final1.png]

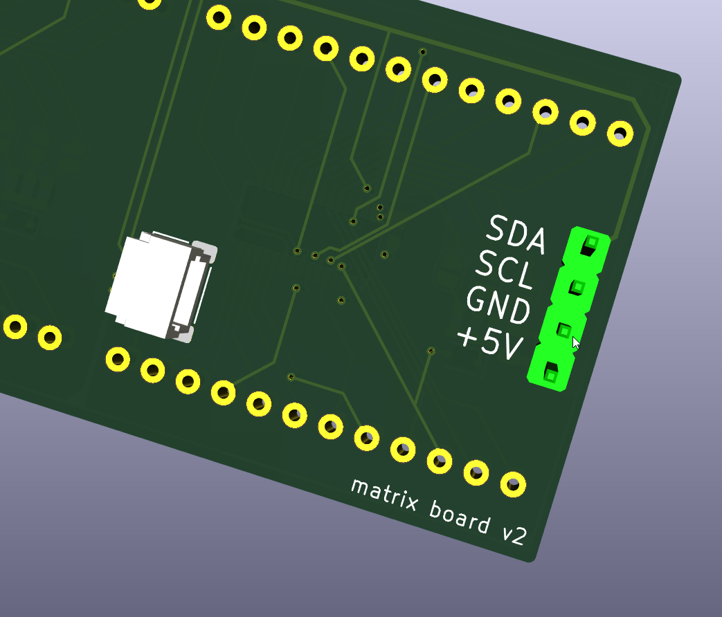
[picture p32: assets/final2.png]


# September 6, 2026: Simple enclosure

I made a really simple enclosure in Onshape. Since I'm very constrained for time, it's quite minimal, but is very similar to the original 3D printed case I used for my matrix clock before any of the PCBs (before v1, see journal_r1.md). It should still be functional and add polish to the project as I added cutouts for the USB and sensors. Battery will basically never need to be replaced, so there's no cutout for that.

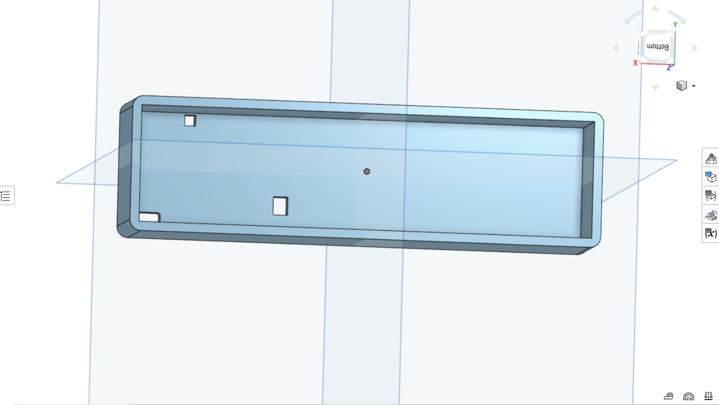
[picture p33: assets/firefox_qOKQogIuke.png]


**Total time spent: 0.6 hours**

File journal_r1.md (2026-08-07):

---
title: "Bicolour Matrix PCB"
author: "Surya"
description: "Red and Green LED 32x8 Matrix with HT16K33A"
created_at: "2025-05-19"
---

# May 19, 2025: Project kickoff and planning

Four years ago, I built a custom clock with off-the-shelf parts (Arduino Nano, DS3231 breakout, 32x8 MAX7219 LED Matrix, all on a breadboard with 2 buttons). Although it has worked very reliably, only needing a few battery replacements and resetting the nano a few times, I want to make a custom solution.

A simple clock with a LED matrix with the current time in a blue case. An Arduino Nano and other components are in the background.
*the current solution ✨*

### Plans
Displays: https://www.aliexpress.com/item/1005007029570407.html
bicolour 8x8 led matrix !! (Red Yellow Green CC)
 \
Controller: Holtek HT16K33A
https://www.holtek.com/webapi/116711/HT16K33Av102.pdf
likely going to take inspiration from here: 
- https://www.adafruit.com/product/902
- https://learn.adafruit.com/adafruit-led-backpack/bi-color-8x8-matrix

Display Schematic (from Adafruit):


Using these connections (no STEMMA connectors, just 4 ICs wired on a PCB to same I2C bus with different addresses hard-set on each IC), I will probably make a similar PCB layout with these segments + a microcontroller (possibly a SMD rp2040-zero) with a RTC module and battery slot + controlls for time adjustment and screen brightness controll + an alarm feature. \
I could also use an ESP32 XIAO board and make a feature to add alarms with your phone (maybe also experiment with Zigbee?). I shall see. \
All rough ideas for now, I have some parts in mind but I will likely have to order the screens and a HT16K33(A) breakout board (https://www.aliexpress.com/item/1005006831500717.html) to see if this idea is feasible. If it is, this will be pretty epic.

**Total time spent: 4 hours**

# May 22, 2025: Ordered components

Ordered the 10 pack of LED matricies and the HT16K33 breakout board. I'll prototype with it and build a schematic based on that. The cost of the other components will likely not be much. Not much else for today.

# May 26, 2025: Researching matrix designs

I found this video a few days ago that popped into my YT rec: https://www.youtube.com/watch?v=7fNYj0EXxMs. The PCB design was shown for a few seconds and its quite interesting since he uses the same Holtek driver (along with an I2C address translator; LTC4316) to drive a row of 8 displays, each with 20 pins: 

I'll try and see what magic was performed here (since idk much about this) and see if I can emulate it !!
update: I decided to just go with 4 ICs chained together this is probably beyond my scope

**Total time spent: 1 hour**

## 2025-05-30
The shipment of the LED matricies and breakout board arrived!! I will assemble them soon (according to the Adafruit schematic) with an arduino nano probably to test. One thing I noticied is that the breakout is kinda sketchy in quality (ive never seen such a thin pcb). Anwyays, it should be fine.



# June 3, 2025: Breadboard prototype works

Finally got time to wire everything together. Took me roughly 2hrs to make all the breadboard connections according to the schematic. But it works!\

I tested using the Adafruit example sketch. There are some buggy sections which I'll have to look into later, but for now it looks promising. I guess it's PCB design time. My updates might be less frequent since I'll be busy with a bunch of things.

**Total time spent: 2.5 hours**

# June 12, 2025: Schematic design

Its been a while (got busy) but finally got around to making the schematic (I made one copy and then copy pasted it 4 times; it should work for now). It took be a bit to import the LED controller IC symbol from easyeda (setting up easyeda2kicad and downloading plugins and stuff). The routing is kinda messy but we ball. Took me roughly 2-3hrs I lost track. 

I downloaded and imported the Adafruit board into KiCad so I can reference it while making mine, but my design will be pretty different since they mounted the display on the back of the PCB (mine will be in the front so the pins are mirrored/flipped)


**Total time spent: 3 hours**

# July 10, 2025: Started PCB layout

OKAY SO life happened. Starting the PCB was quite intimidating so I kind of clicked switch to PCB and left the project for a month. BUT I have convinced myself to get started. And yes it is a lot harder than I thought routing this is pretty pain since I've only done HC solder before. Will prob have to use a lot of vias. Not dealing with any important signals so I should be fine for the most part. \
Slight time skip but no picture for now since I had to delete all my traces a few times. Will be slaving away at this tomorrow.

**Total time spent: 3 hours**

# July 11, 2025: PCB routing progress

Some progress. Was pain, idk what I'm doing. Not much to say. Took me roughly an hour or 2. 


**Total time spent: 2 hours**

# July 13, 2025: Footprint mistake

OKAY SO AFTER GOING THROUGH ALL THAT... I was using the SOP28 footprint for the LED driver when I meant to use SSOP28. Welp.. time to restart the routing again. Actually I'll do this tomorrow I'm tired.

**Total time spent: 1 hour**

# July 14, 2025: Routing practice paying off

Honestly after this much practice, this is becoming not as hard anymore !! \
managed to get some decent progress:


**Total time spent: 2 hours**

# July 15, 2025: First module layout done

Finally pretty much done one module, but now I've realized that I can't really copy-paste the design over. I gotta use layout replication (https://www.youtube.com/watch?v=DBfI2wwno5o) and using a custom goofy schematic size wasn't the best idea. I thought I could get away with the jank 😔. I will do that soon. I will also upload the PCB to this repo soon but I'm editing this on WSL and my project folder is on Windows so I got a bit lazy in doing that until now.


**Total time spent: 2 hours**

# August 10, 2025: Layout replication setup

I just restarting working on it :pf:. Yet again got busy. Anyways, finally setup the replicate layout plugin (the guide was useful) and managed to 4x the layout properly. It took quite a while. I have yet to put the routing for connecting them all together, (and I still have no clue what I'm doing) but overall good progress today.

**Total time spent: 2 hours**

# August 12, 2025: Routing improvements

Got some feedback from a friend and adjusted my routing a bit, and also synced it with the other 4 modules. I tried to route the power/gnd/i2c lines but my routing seems very sketchy. I'll try to improve on it tomorrow. Not much else to say.


**Total time spent: 1 hour**

# August 13, 2025: Ground stitching vias

I got some feedback from the Slack and added stitching vias to my ground plane (I did not know these were a thing). I also improved my layout further in terms of connecting it all together and adding polish (rounded corners, silkscreen, fixing small DRC warnings, etc.).

**Total time spent: 1.5 hours**

# August 15, 2025: Final verification and adapter board

Got some more feedback and everything seems to be good. I will verify the connections in the schematic a last time before I mark this part of the project as done. I also created the project and for now the schematic for the adapter/driver board to make a simple but smart clock. I'll add my sketches later but the 2 boards will probably be the same size with standard headers and I can right angle mount a top board with 2 headers using some right angle header pins I have. I just have to make sure the measurements are right.

**Total time spent: 1 hour**

# August 19, 2025: Adapter board schematic and PCB progress

Just started to work on the adapter board. The schematic was quite easy to make but had to make a real quick custom symbol for the DS3231 module I already had. It's slightly scuffed but not too bad. I'm thinking of using an ESP32 as clicking a bunch of buttons to set an alarm seems cumbersome especially since I usually don't have a static alarm time. It feels like something easier set on your phone. I don't have much more time today so I will start the PCB tomorrow.


I thought of adding a small breadboard-style layout to the PCB if i wanted to tack on some components in the future with some wires. Made a quick custom footprint for that (and random symbol since it doesn't really matter).

I started work on the PCB and I've gotten decent progress. I want to power the thing through the USB on the ESP32, so I am trying to add clearance for that. The range doesn't have to be amazing since I very likely won't be setting my alarm from another room. This is more of a personally tailored PCB rather than something that suits everyone.

**Total time spent: 3 hours**

# August 21, 2025: Adapter board buttons and prototype verification

I originally only allocated space for 2 buttons, but later changed it to 4, since I'll probably need more for the function I want. I don't like the idea of having the time to be dependent on the internet, so I'd like the option to set time time up up/down controls, a button to switch the display colours and a button to toggle/snooze the alarm. I am mostly done the PCB I believe.



I realized my prototype I made a whie ago wasn't really working properly so I got a bit worried and decided to rewire the entire thing according to the schematic. Turns out I misread a pin due to the bad silkscreen on the breakout board I got... so now it actually works. At least now I have confirmation my schematic works. I also wired up the RTC module and used claude to make a quick test program; everything works fine!! (extra stuff in picture is from other projects/random leftovers)


**Total time spent: 3.5 hours**

# August 22, 2025: Button board complete

Last stretch is the button board, which was very easy to make, just a basic schematic. I measured how long the pinheader would be with my callipers (gap between the adapter and matrix PCB) and its around 18mm, so I made the board roughly that long. Slap in a gound plane and pin socket and simple routing and its done. I should finally be done... yippee !!


**Total time spent: 1 hour**

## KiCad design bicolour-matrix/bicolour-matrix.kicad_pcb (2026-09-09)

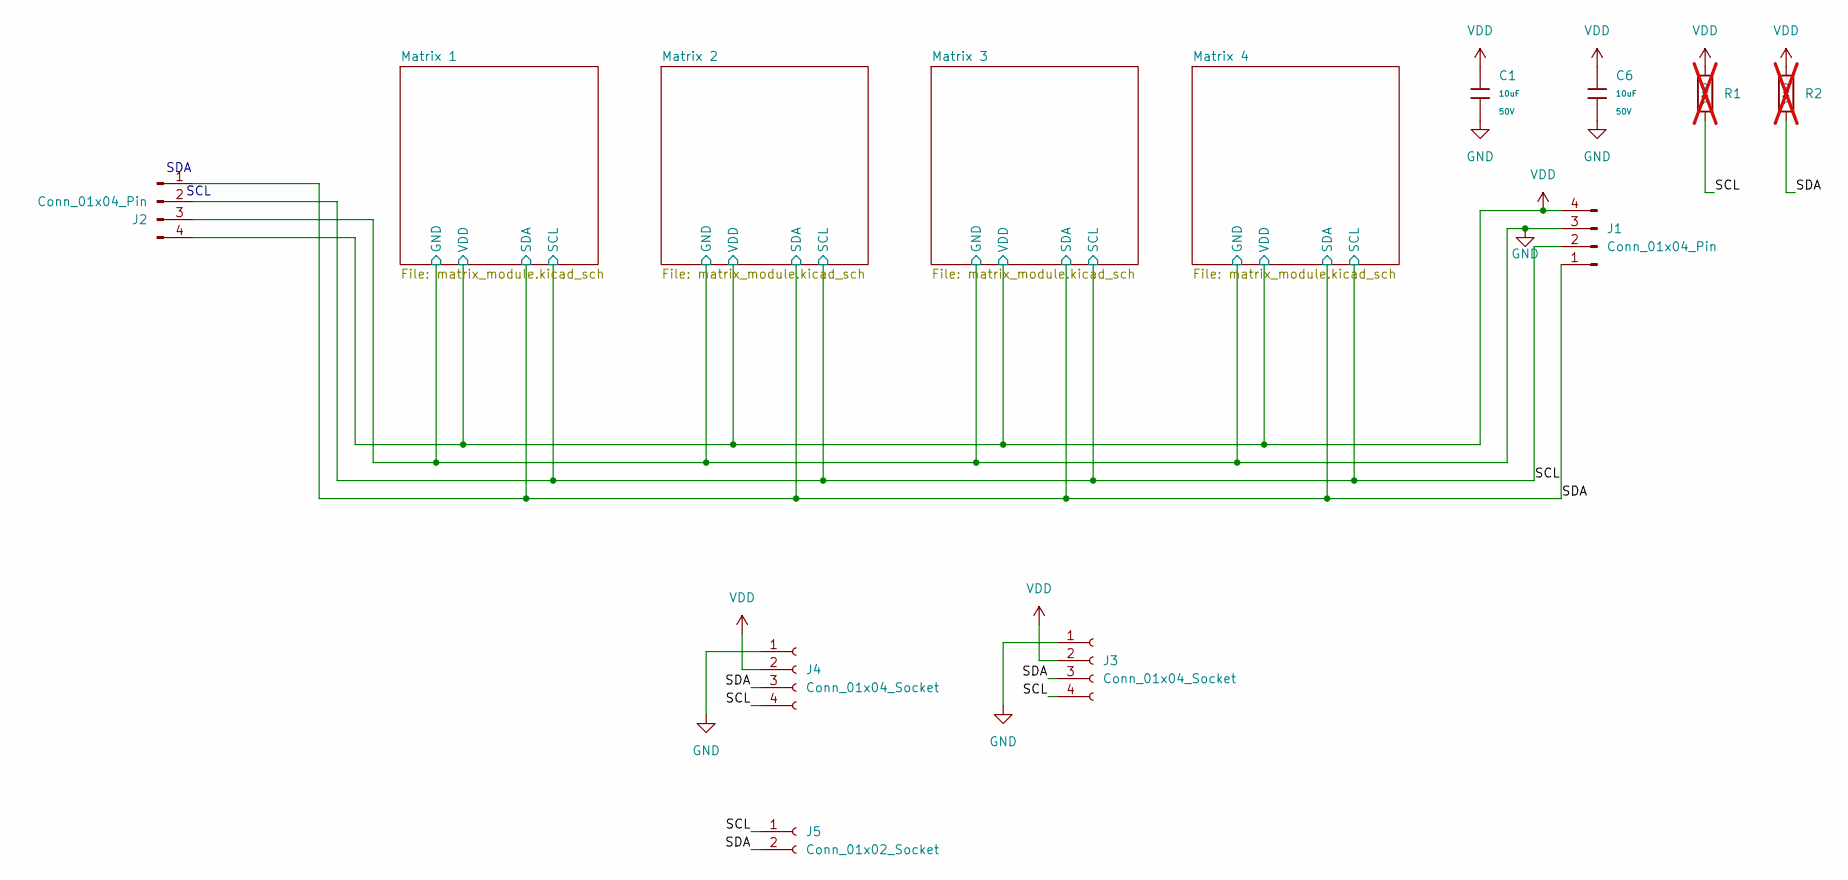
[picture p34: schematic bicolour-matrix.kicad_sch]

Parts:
C1, C6: 10uF; C_0805; Voltage Rated 50V; Tolerance ±10%; Part GRM21BR61H106KE43L; LCSC C440198
J1, J2: Conn_01x04_Pin; PinHeader_1x04_P2.54mm_Vertical
J3, J4: Conn_01x04_Socket; JST_SH_SM04B-SRSS-TB_1x04-1MP_P1.00mm_Horizontal
J5: Conn_01x02_Socket; PinSocket_1x02_P2.54mm_Vertical
R1, R2: 10kΩ; R_0603_1608Metric; Overload Voltage (Max) 75V; Tolerance ±1%; Part 0603WAF1002T5E; LCSC C25804; not fitted

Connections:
/SCL: J1.2, J2.2, J3.4, J4.4, J5.1, R1.2; also elsewhere on the board
/SDA: J1.1, J2.1, J3.3, J4.3, J5.2, R2.2; also elsewhere on the board
GND: C1.2, C6.2, J1.3, J2.3, J3.1, J4.1; also elsewhere on the board
VDD: C1.1, C6.1, J1.4, J2.4, J3.2, J4.2, R1.1, R2.1; also elsewhere on the board

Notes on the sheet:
SDA
SCL

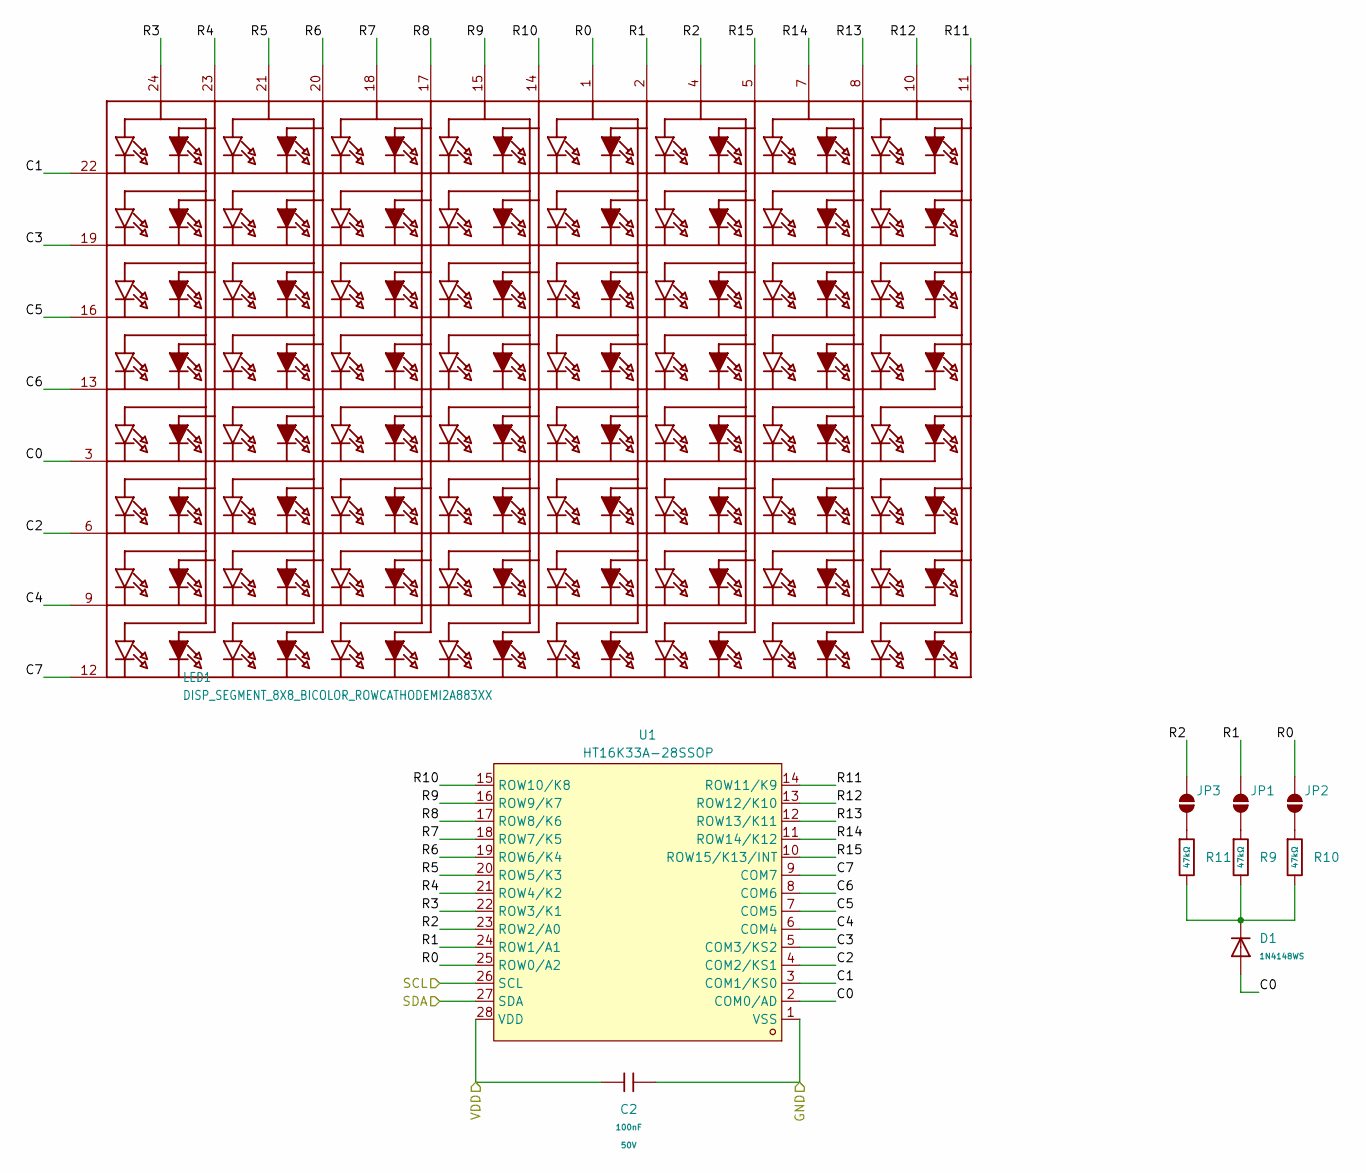
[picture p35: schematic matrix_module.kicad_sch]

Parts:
C2: 100nF; C_0603; Voltage Rated 50V; Tolerance ±10%; Part CC0603KRX7R9BB104; LCSC C14663
D1: 1N4148WS; D_SOD-323; Forward Voltage (Vf@If) 1.25V@150mA; Reverse Voltage (Vr) 100V; Part 1N4148WS; LCSC C2128
JP1, JP2, JP3: SolderJumper_2_Open; SolderJumper-2_P1.3mm_Open_RoundedPad1.0x1.5mm
LED1: DISP_SEGMENT_8X8_BICOLOR_ROWCATHODEMI2A883XX; SEGMENT_BICOL_BL-M12A883XX
R9, R10, R11: 47kΩ; R_0603; Overload Voltage (Max) 75V; Tolerance ±1%; Part 0603WAF4702T5E; LCSC C25819
U1: HT16K33A-28SSOP; SSOP-28_3.9x9.9mm_P0.635mm; LCSC Part C5444738

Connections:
/Matrix 1/C0: D1.2, LED1.3 (K5), U1.2 (COM0/AD)
/Matrix 1/C1: LED1.22 (K1), U1.3 (COM1/KS0)
/Matrix 1/C2: LED1.6 (K6), U1.4 (COM2/KS1)
/Matrix 1/C3: LED1.19 (K2), U1.5 (COM3/KS2)
/Matrix 1/C4: LED1.9 (K7), U1.6 (COM4)
/Matrix 1/C5: LED1.16 (K3), U1.7 (COM5)
/Matrix 1/C6: LED1.13 (K4), U1.8 (COM6)
/Matrix 1/C7: LED1.12 (K8), U1.9 (COM7)
/Matrix 1/R0: JP2.2 (B), LED1.1 (A9), U1.25 (ROW0/A2)
/Matrix 1/R1: JP1.2 (B), LED1.2 (A10), U1.24 (ROW1/A1)
/Matrix 1/R2: JP3.2 (B), LED1.4 (A11), U1.23 (ROW2/A0)
/Matrix 1/R3: LED1.24 (A1), U1.22 (ROW3/K1)
/Matrix 1/R4: LED1.23 (A2), U1.21 (ROW4/K2)
/Matrix 1/R5: LED1.21 (A3), U1.20 (ROW5/K3)
/Matrix 1/R6: LED1.20 (A4), U1.19 (ROW6/K4)
/Matrix 1/R7: LED1.18 (A5), U1.18 (ROW7/K5)
/Matrix 1/R8: LED1.17 (A6), U1.17 (ROW8/K6)
/Matrix 1/R9: LED1.15 (A7), U1.16 (ROW9/K7)
/Matrix 1/R10: LED1.14 (A8), U1.15 (ROW10/K8)
/Matrix 1/R11: LED1.11 (A16), U1.14 (ROW11/K9)
/Matrix 1/R12: LED1.10 (A15), U1.13 (ROW12/K10)
/Matrix 1/R13: LED1.8 (A14), U1.12 (ROW13/K11)
/Matrix 1/R14: LED1.7 (A13), U1.11 (ROW14/K12)
/Matrix 1/R15: LED1.5 (A12), U1.10 (ROW15/K13/INT)
/SCL: U1.26 (SCL); also elsewhere on the board
/SDA: U1.27 (SDA); also elsewhere on the board
GND: C2.2, U1.1 (VSS); also elsewhere on the board
unnamed: D1.1, R9.2, R10.2, R11.2
unnamed: JP1.1 (A), R9.1
unnamed: JP2.1 (A), R10.1
unnamed: JP3.1 (A), R11.1
VDD: C2.1, U1.28 (VDD); also elsewhere on the board

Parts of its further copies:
C3, C4, C5: 100nF; C_0603; Voltage Rated 50V; Tolerance ±10%; Part CC0603KRX7R9BB104; LCSC C14663
D2, D3, D4: 1N4148WS; D_SOD-323; Forward Voltage (Vf@If) 1.25V@150mA; Reverse Voltage (Vr) 100V; Part 1N4148WS; LCSC C2128
JP4, JP5, JP6, JP7, JP8, JP9, JP10, JP11, JP12: SolderJumper_2_Open; SolderJumper-2_P1.3mm_Open_RoundedPad1.0x1.5mm
LED2, LED3, LED4: DISP_SEGMENT_8X8_BICOLOR_ROWCATHODEMI2A883XX; SEGMENT_BICOL_BL-M12A883XX
R3, R4, R5, R13, R14, R15, R18, R19, R20: 47kΩ; R_0603; Overload Voltage (Max) 75V; Tolerance ±1%; Part 0603WAF4702T5E; LCSC C25819
U2, U3, U4: HT16K33A-28SSOP; SSOP-28_3.9x9.9mm_P0.635mm; LCSC Part C5444738

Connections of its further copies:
/Matrix 2/C0: D2.2, LED2.3 (K5), U2.2 (COM0/AD)
/Matrix 2/C1: LED2.22 (K1), U2.3 (COM1/KS0)
/Matrix 2/C2: LED2.6 (K6), U2.4 (COM2/KS1)
/Matrix 2/C3: LED2.19 (K2), U2.5 (COM3/KS2)
/Matrix 2/C4: LED2.9 (K7), U2.6 (COM4)
/Matrix 2/C5: LED2.16 (K3), U2.7 (COM5)
/Matrix 2/C6: LED2.13 (K4), U2.8 (COM6)
/Matrix 2/C7: LED2.12 (K8), U2.9 (COM7)
/Matrix 2/R0: JP6.2 (B), LED2.1 (A9), U2.25 (ROW0/A2)
/Matrix 2/R1: JP5.2 (B), LED2.2 (A10), U2.24 (ROW1/A1)
/Matrix 2/R2: JP4.2 (B), LED2.4 (A11), U2.23 (ROW2/A0)
/Matrix 2/R3: LED2.24 (A1), U2.22 (ROW3/K1)
/Matrix 2/R4: LED2.23 (A2), U2.21 (ROW4/K2)
/Matrix 2/R5: LED2.21 (A3), U2.20 (ROW5/K3)
/Matrix 2/R6: LED2.20 (A4), U2.19 (ROW6/K4)
/Matrix 2/R7: LED2.18 (A5), U2.18 (ROW7/K5)
/Matrix 2/R8: LED2.17 (A6), U2.17 (ROW8/K6)
/Matrix 2/R9: LED2.15 (A7), U2.16 (ROW9/K7)
/Matrix 2/R10: LED2.14 (A8), U2.15 (ROW10/K8)
/Matrix 2/R11: LED2.11 (A16), U2.14 (ROW11/K9)
/Matrix 2/R12: LED2.10 (A15), U2.13 (ROW12/K10)
/Matrix 2/R13: LED2.8 (A14), U2.12 (ROW13/K11)
/Matrix 2/R14: LED2.7 (A13), U2.11 (ROW14/K12)
/Matrix 2/R15: LED2.5 (A12), U2.10 (ROW15/K13/INT)
/Matrix 3/C0: D3.2, LED3.3 (K5), U3.2 (COM0/AD)
/Matrix 3/C1: LED3.22 (K1), U3.3 (COM1/KS0)
/Matrix 3/C2: LED3.6 (K6), U3.4 (COM2/KS1)
/Matrix 3/C3: LED3.19 (K2), U3.5 (COM3/KS2)
/Matrix 3/C4: LED3.9 (K7), U3.6 (COM4)
/Matrix 3/C5: LED3.16 (K3), U3.7 (COM5)
/Matrix 3/C6: LED3.13 (K4), U3.8 (COM6)
/Matrix 3/C7: LED3.12 (K8), U3.9 (COM7)
/Matrix 3/R0: JP9.2 (B), LED3.1 (A9), U3.25 (ROW0/A2)
/Matrix 3/R1: JP8.2 (B), LED3.2 (A10), U3.24 (ROW1/A1)
/Matrix 3/R2: JP7.2 (B), LED3.4 (A11), U3.23 (ROW2/A0)
/Matrix 3/R3: LED3.24 (A1), U3.22 (ROW3/K1)
/Matrix 3/R4: LED3.23 (A2), U3.21 (ROW4/K2)
/Matrix 3/R5: LED3.21 (A3), U3.20 (ROW5/K3)
/Matrix 3/R6: LED3.20 (A4), U3.19 (ROW6/K4)
/Matrix 3/R7: LED3.18 (A5), U3.18 (ROW7/K5)
/Matrix 3/R8: LED3.17 (A6), U3.17 (ROW8/K6)
/Matrix 3/R9: LED3.15 (A7), U3.16 (ROW9/K7)
/Matrix 3/R10: LED3.14 (A8), U3.15 (ROW10/K8)
/Matrix 3/R11: LED3.11 (A16), U3.14 (ROW11/K9)
/Matrix 3/R12: LED3.10 (A15), U3.13 (ROW12/K10)
/Matrix 3/R13: LED3.8 (A14), U3.12 (ROW13/K11)
/Matrix 3/R14: LED3.7 (A13), U3.11 (ROW14/K12)
/Matrix 3/R15: LED3.5 (A12), U3.10 (ROW15/K13/INT)
/Matrix 4/C0: D4.2, LED4.3 (K5), U4.2 (COM0/AD)
/Matrix 4/C1: LED4.22 (K1), U4.3 (COM1/KS0)
/Matrix 4/C2: LED4.6 (K6), U4.4 (COM2/KS1)
/Matrix 4/C3: LED4.19 (K2), U4.5 (COM3/KS2)
/Matrix 4/C4: LED4.9 (K7), U4.6 (COM4)
/Matrix 4/C5: LED4.16 (K3), U4.7 (COM5)
/Matrix 4/C6: LED4.13 (K4), U4.8 (COM6)
/Matrix 4/C7: LED4.12 (K8), U4.9 (COM7)
/Matrix 4/R0: JP12.2 (B), LED4.1 (A9), U4.25 (ROW0/A2)
/Matrix 4/R1: JP11.2 (B), LED4.2 (A10), U4.24 (ROW1/A1)
/Matrix 4/R2: JP10.2 (B), LED4.4 (A11), U4.23 (ROW2/A0)
/Matrix 4/R3: LED4.24 (A1), U4.22 (ROW3/K1)
/Matrix 4/R4: LED4.23 (A2), U4.21 (ROW4/K2)
/Matrix 4/R5: LED4.21 (A3), U4.20 (ROW5/K3)
/Matrix 4/R6: LED4.20 (A4), U4.19 (ROW6/K4)
/Matrix 4/R7: LED4.18 (A5), U4.18 (ROW7/K5)
/Matrix 4/R8: LED4.17 (A6), U4.17 (ROW8/K6)
/Matrix 4/R9: LED4.15 (A7), U4.16 (ROW9/K7)
/Matrix 4/R10: LED4.14 (A8), U4.15 (ROW10/K8)
/Matrix 4/R11: LED4.11 (A16), U4.14 (ROW11/K9)
/Matrix 4/R12: LED4.10 (A15), U4.13 (ROW12/K10)
/Matrix 4/R13: LED4.8 (A14), U4.12 (ROW13/K11)
/Matrix 4/R14: LED4.7 (A13), U4.11 (ROW14/K12)
/Matrix 4/R15: LED4.5 (A12), U4.10 (ROW15/K13/INT)
/SCL: U2.26 (SCL), U3.26 (SCL), U4.26 (SCL); also elsewhere on the board
/SDA: U2.27 (SDA), U3.27 (SDA), U4.27 (SDA); also elsewhere on the board
GND: C3.2, C4.2, C5.2, U2.1 (VSS), U3.1 (VSS), U4.1 (VSS); also elsewhere on the board
unnamed: D2.1, R3.2, R4.2, R5.2
unnamed: D3.1, R13.2, R14.2, R15.2
unnamed: D4.1, R18.2, R19.2, R20.2
unnamed: JP4.1 (A), R3.1
unnamed: JP5.1 (A), R4.1
unnamed: JP6.1 (A), R5.1
unnamed: JP7.1 (A), R13.1
unnamed: JP8.1 (A), R14.1
unnamed: JP9.1 (A), R15.1
unnamed: JP10.1 (A), R18.1
unnamed: JP11.1 (A), R19.1
unnamed: JP12.1 (A), R20.1
VDD: C3.1, C4.1, C5.1, U2.28 (VDD), U3.28 (VDD), U4.28 (VDD); also elsewhere on the board

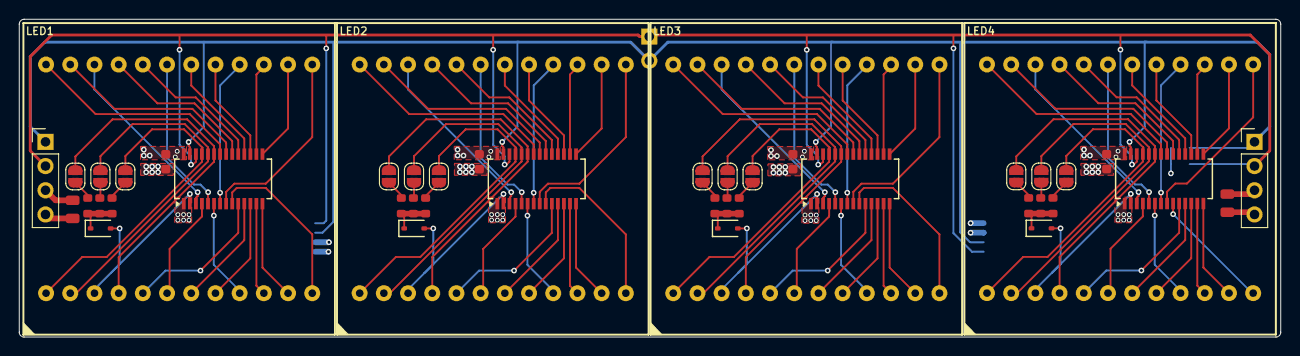
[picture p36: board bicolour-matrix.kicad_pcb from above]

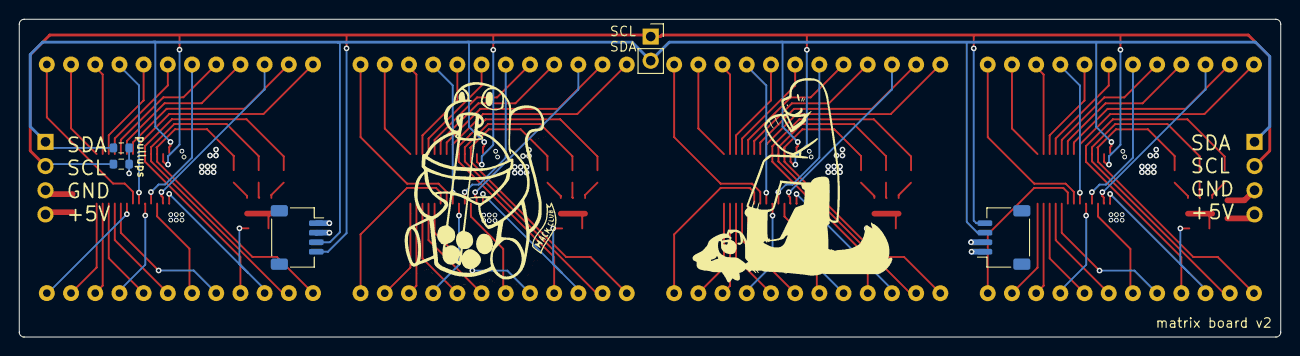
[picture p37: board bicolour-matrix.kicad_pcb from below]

Board: 4 copper layers, 132.4 x 33.4 mm, 49 parts (5 on the bottom side), 116 nets.

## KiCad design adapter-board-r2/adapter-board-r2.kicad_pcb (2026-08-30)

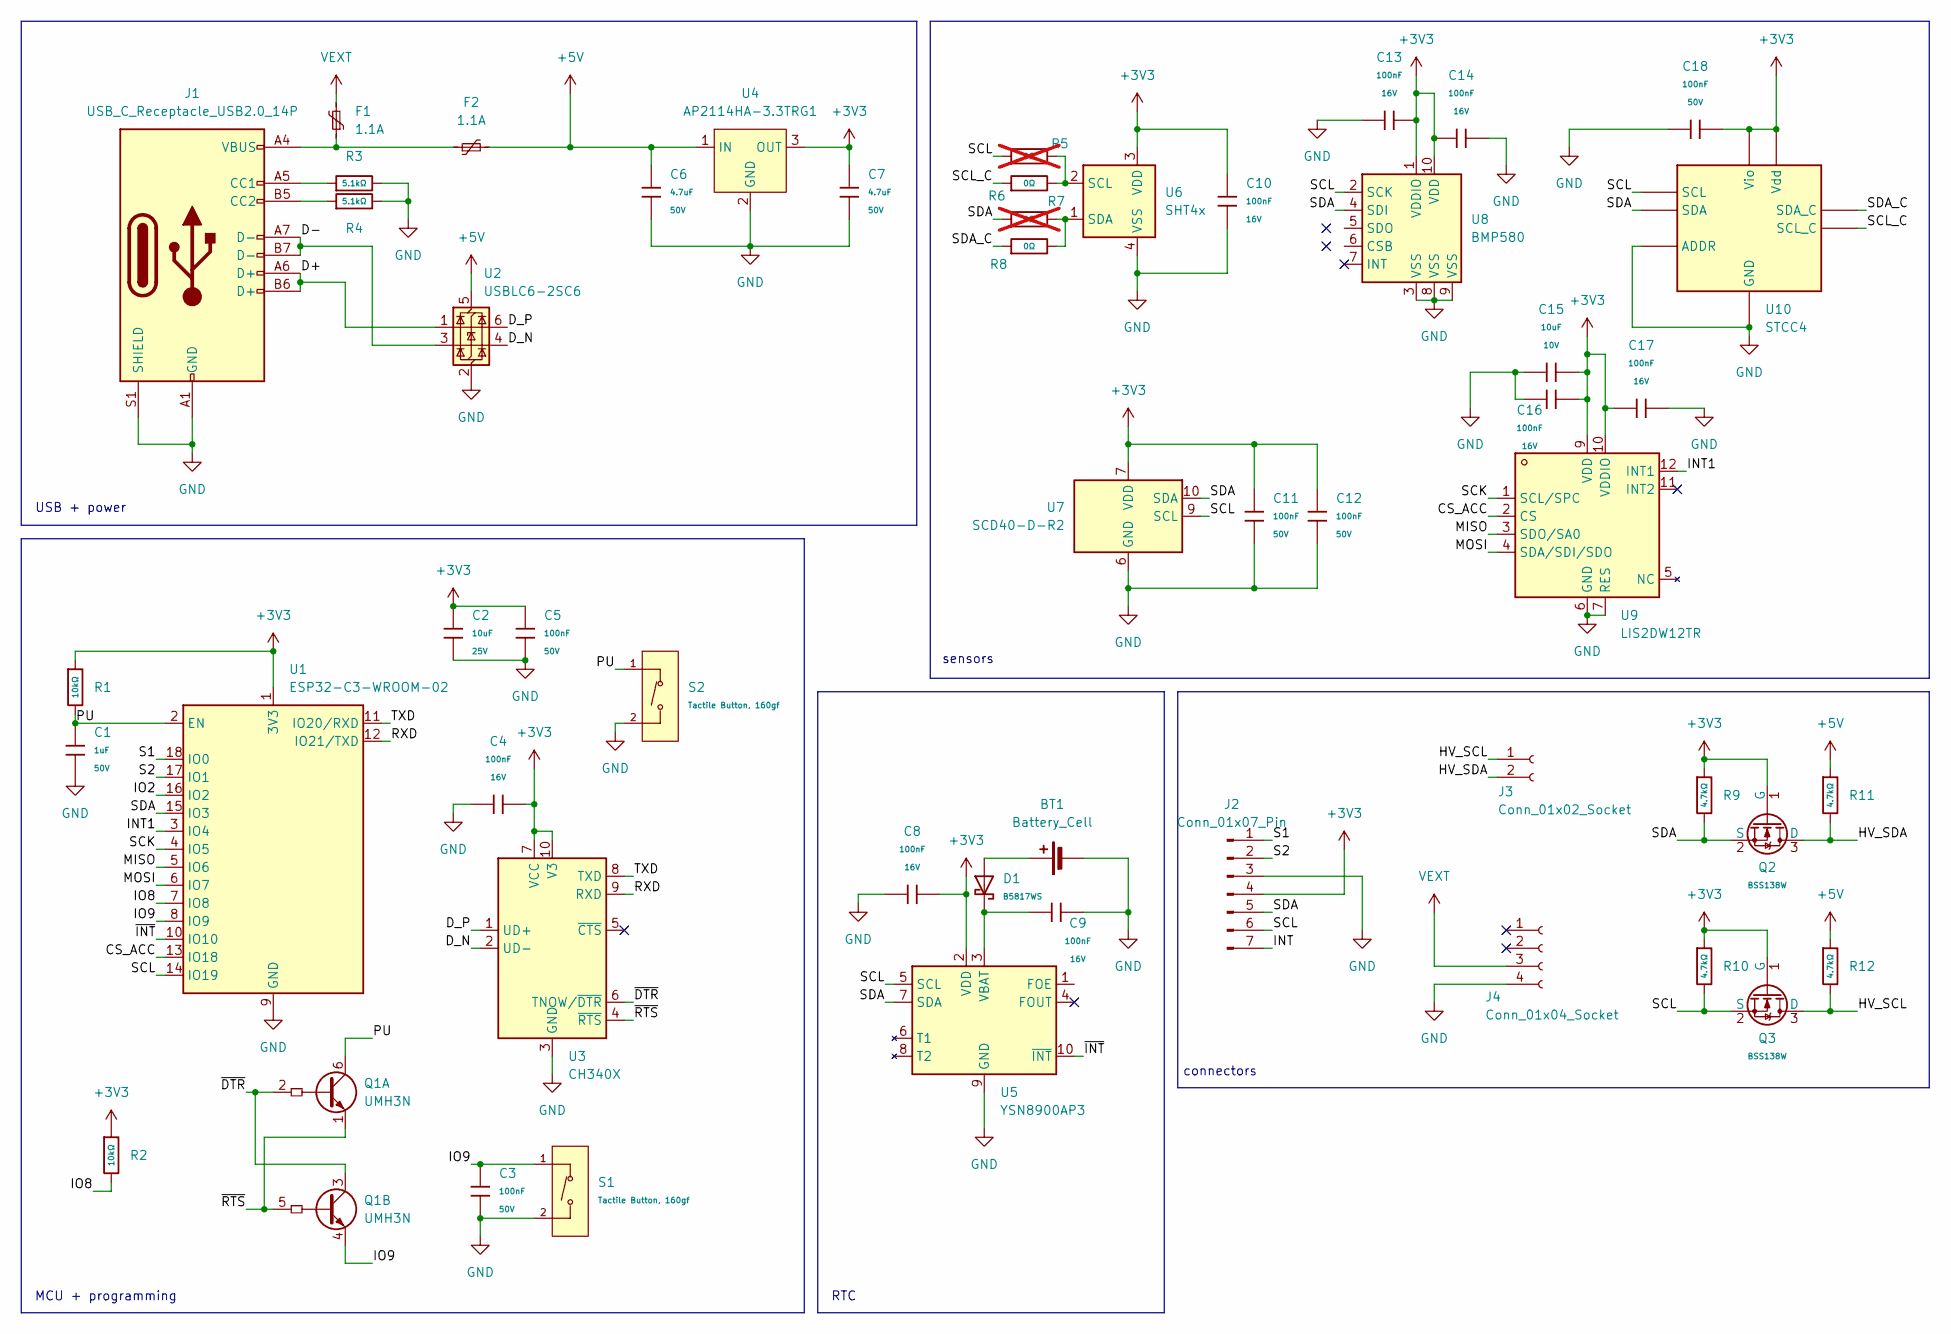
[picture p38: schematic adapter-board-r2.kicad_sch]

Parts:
BT1: Battery_Cell; BatteryHolder_Keystone_1060_1x2032
C1: 1uF; C_0603; Voltage Rated 50V; Tolerance ±10%; Part CL10A105KB8NNNC; LCSC C15849
C2: 10uF; C_0805; Voltage Rated 25V; Tolerance ±10%; Part CL21A106KAYNNNE; LCSC C15850
C3, C5, C11, C12, C18: 100nF; C_0603; Voltage Rated 50V; Tolerance ±10%; Part CC0603KRX7R9BB104; LCSC C14663
C4, C8, C9, C10, C13, C14, C16, C17: 100nF; C_0402; Voltage Rated 16V; Tolerance ±10%; Part CL05B104KO5NNNC; LCSC C1525
C6, C7: 4.7uF; C_1206; Voltage Rated 50V; Tolerance ±10%; Part 1206B475K500NT; LCSC C29823
C15: 10uF; C_0603; Voltage Rated 10V; Tolerance ±10%; Part CL10A106KP8NNNC; LCSC C19702
D1: B5817WS; D_SOD-323; Forward Voltage (Vf@If) 450mV@1.0A; Reverse Voltage (Vr) 20V; Part B5817WS; LCSC C7420329
F1, F2: 1.1A; Fuse_0805_2012Metric
J1: USB_C_Receptacle_USB2.0_14P; USB-C-TH_SHOUHAN_TYPE-C-14PLC-H10.0
J2: Conn_01x07_Pin; JST_SH_SM07B-SRSS-TB_1x07-1MP_P1.00mm_Horizontal
J3: Conn_01x02_Socket; PinSocket_1x02_P2.54mm_Vertical
J4: Conn_01x04_Socket; PinSocket_1x04_P2.54mm_Vertical
Q1: UMH3N; SOT-363_SC-70-6
Q2, Q3: BSS138W; SOT-323_SC-70; Part BSS138W; LCSC C28646265
R1, R2: 10kΩ; R_0603; Overload Voltage (Max) 75V; Tolerance ±1%; Part 0603WAF1002T5E; LCSC C25804
R3, R4: 5.1kΩ; R_0603; Overload Voltage (Max) 75V; Tolerance ±1%; Part 0603WAF5101T5E; LCSC C23186
R5, R7: 0Ω; R_0402; Overload Voltage (Max) 50V; Tolerance ±1%; Part 0402WGF0000TCE; LCSC C17168; not fitted
R6, R8: 0Ω; R_0402; Overload Voltage (Max) 50V; Tolerance ±1%; Part 0402WGF0000TCE; LCSC C17168
R9, R10, R11, R12: 4.7kΩ; R_0603; Overload Voltage (Max) 75V; Tolerance ±1%; Part 0603WAF4701T5E; LCSC C23162
S1, S2: Tactile Button, 160gf; SW_SPST_PTS810; Voltage Rating (Dc) 12V; Part TS-1088-AR02016; LCSC C720477
U1: ESP32-C3-WROOM-02
U2: USBLC6-2SC6; SOT-23-6
U3: CH340X; MSOP-10_3x3mm_P0.5mm
U4: AP2114HA-3.3TRG1; SOT-223; LCSC Part C460314
U5: YSN8900AP3; OSC-SMD_10P-L3.2-W2.5-BL_RX8130CE; MPN YSN8900AP3; LCSC Part C54780223
U6: SHT4x; Sensirion_DFN-4_1.5x1.5mm_P0.8mm_SHT4x_NoCentralPad
U7: SCD40-D-R2; Sensirion_SCD4x-1EP_10.1x10.1mm_P1.25mm_EP4.8x4.8mm
U8: BMP580; LGA-10_L2.0-W2.0-P0.50-TL_BMP580; MPN BMP580; LCSC Part C22391138
U9: LIS2DW12TR; LGA-12_2x2mm_P0.5mm; MPN LIS2DW12TR; LCSC Part C189624
U10: STCC4; LCSC C49191471

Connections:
+3V3: C2.1, C4.2, C5.1, C7.1, C8.2, C10.1, C11.1, C12.1, C13.2, C14.1, C15.2, C16.2, C17.1, C18.2, J2.4, Q2.1 (G), Q3.1 (G), R1.1, R2.1, R9.1, R10.1, U1.1 (3V3), U3.7 (VCC), U3.10 (V3), U4.3 (OUT), U5.2 (VDD), U6.3 (VDD), U7.7 (VDD), U7.19 (VDD), U8.1 (VDDIO), U8.10 (VDD), U9.9 (VDD), U9.10 (VDDIO), U10.6 (Vio), U10.7 (Vdd)
+5V: C6.1, F2.2, R11.1, R12.1, U2.5 (VBUS), U4.1 (IN)
/CS_ACC: U1.13 (IO18), U9.2 (CS)
/D+: J1.A6 (D+), J1.B6 (D+), U2.1 (I/O1)
/D-: J1.A7 (D-), J1.B7 (D-), U2.3 (I/O2)
/D_N: U2.4 (I/O2), U3.2 (UD-)
/D_P: U2.6 (I/O1), U3.1 (UD+)
/HV_SCL: J3.1, Q3.3 (D), R12.2
/HV_SDA: J3.2, Q2.3 (D), R11.2
/INT: J2.7
/INT1: U1.3 (IO4), U9.12 (INT1)
/IO2: U1.16 (IO2)
/IO8: R2.2, U1.7 (IO8)
/IO9: C3.1, Q1.4 (E2), S1.1 (A), U1.8 (IO9)
/MISO: U1.5 (IO6), U9.3 (SDO/SA0)
/MOSI: U1.6 (IO7), U9.4 (SDA/SDI/SDO)
/PU: C1.1, Q1.6 (C1), R1.2, S2.1 (A), U1.2 (EN)
/RXD: U1.12 (IO21/TXD), U3.9 (RXD)
/S1: J2.1, U1.18 (IO0)
/S2: J2.2, U1.17 (IO1)
/SCK: U1.4 (IO5), U9.1 (SCL/SPC)
/SCL: J2.6, Q3.2 (S), R5.1, R10.2, U1.14 (IO19), U5.5 (SCL), U7.9 (SCL), U8.2 (SCK), U10.1 (SCL)
/SCL_C: R6.1, U10.8 (SCL_C)
/SDA: J2.5, Q2.2 (S), R7.1, R9.2, U1.15 (IO3), U5.7 (SDA), U7.10 (SDA), U8.4 (SDI), U10.5 (SDA)
/SDA_C: R8.1, U10.2 (SDA_C)
/TXD: U1.11 (IO20/RXD), U3.8 (TXD)
/~DTR: Q1.2 (B1), Q1.3 (C2), U3.6 (TNOW/~DTR)
/~INT: U1.10 (IO10), U5.10 (~INT)
/~RTS: Q1.1 (E1), Q1.5 (B2), U3.4 (~RTS)
GND: BT1.2 (-), C1.2, C2.2, C3.2, C4.1, C5.2, C6.2, C7.2, C8.1, C9.2, C10.2, C11.2, C12.2, C13.1, C14.2, C15.1, C16.1, C17.2, C18.1, J1.A1 (GND), J1.A12 (GND), J1.B1 (GND), J1.B12 (GND), J1.S1 (SHIELD), J2.3, J4.4, R3.2, R4.2, S1.2 (B), S2.2 (B), U1.9 (GND), U1.19 (GND), U2.2 (GND), U3.3 (GND), U4.2 (GND), U4.4 (GND), U5.9 (GND), U6.4 (VSS), U7.6 (GND), U7.20 (GND), U7.21 (GND), U8.3 (VSS), U8.8 (VSS), U8.9 (VSS), U9.6 (GND), U9.7 (RES), U9.8 (GND), U10.3 (ADDR), U10.4 (GND)
unnamed: BT1.1 (+), D1.2
unnamed: F1.1, F2.1, J1.A4 (VBUS), J1.A9 (VBUS), J1.B4 (VBUS), J1.B9 (VBUS)
unnamed: J1.A5 (CC1), R3.1
unnamed: J1.B5 (CC2), R4.1
unnamed: C9.1, D1.1, U5.3 (VBAT)
unnamed: R5.2, R6.2, U6.2 (SCL)
unnamed: R7.2, R8.2, U6.1 (SDA)
VEXT: F1.2, J4.3

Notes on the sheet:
sensors
MCU + programming
RTC
connectors
USB + power

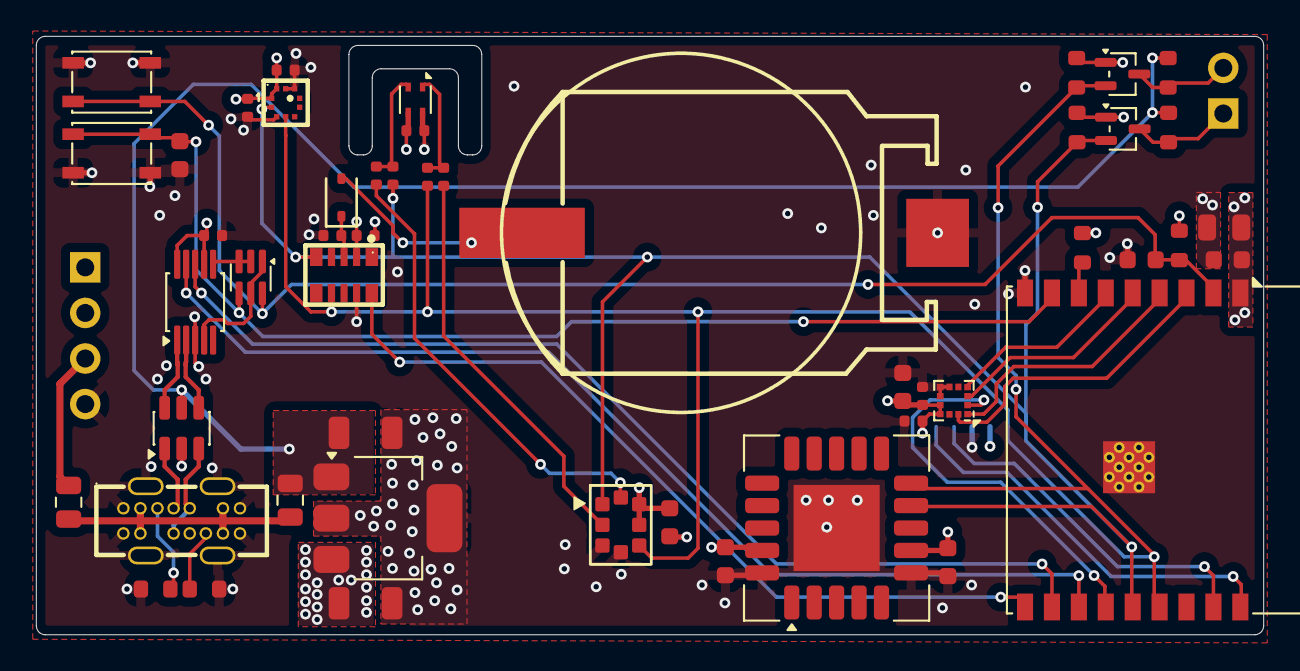
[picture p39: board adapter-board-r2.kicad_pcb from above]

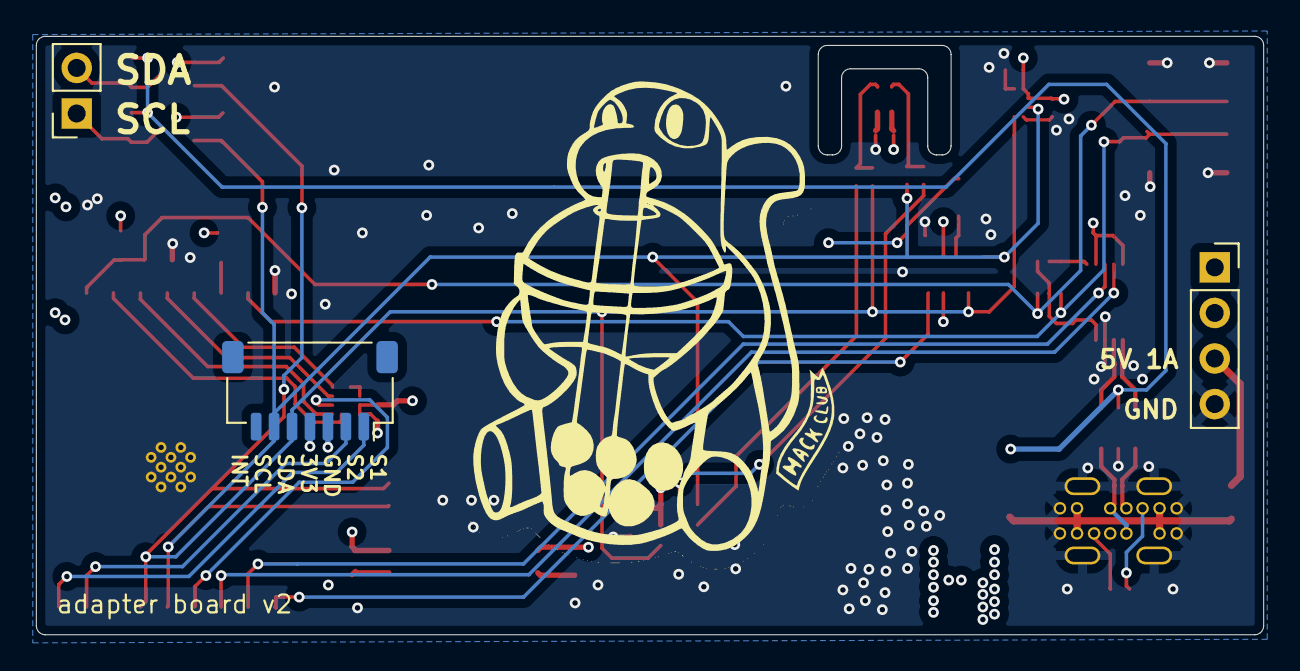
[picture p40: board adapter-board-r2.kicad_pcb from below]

Board: 4 copper layers, 68.4 x 33.3 mm, 53 parts (3 on the bottom side), 36 nets.

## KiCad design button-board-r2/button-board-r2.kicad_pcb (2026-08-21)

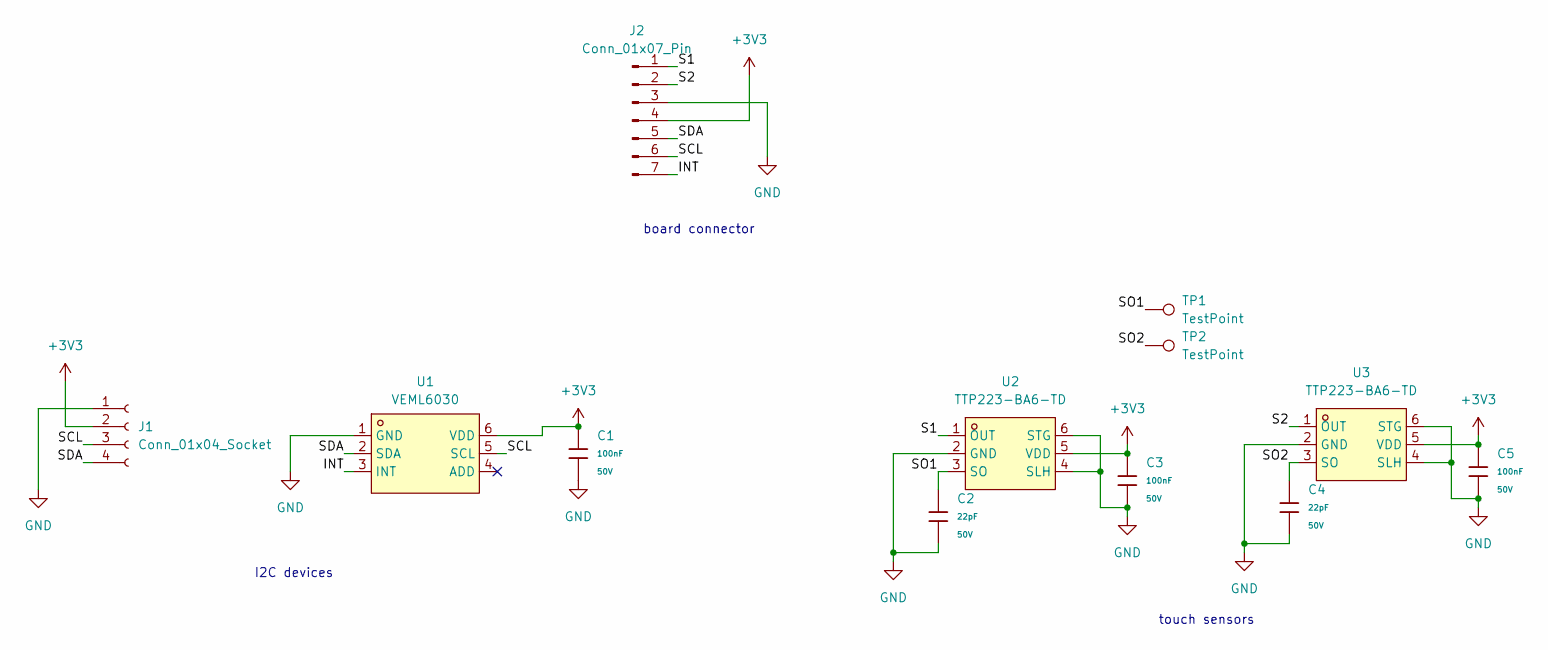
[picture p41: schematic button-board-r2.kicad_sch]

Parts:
C1, C3, C5: 100nF; C_0603; Voltage Rated 50V; Tolerance ±10%; Part CC0603KRX7R9BB104; LCSC C14663
C2, C4: 22pF; C_0603; Voltage Rated 50V; Tolerance ±5%; Part CL10C220JB8NNNC; LCSC C1653
J1: Conn_01x04_Socket; SSD1306-0.91-OLED-4pin-128x32
J2: Conn_01x07_Pin; JST_SH_SM07B-SRSS-TB_1x07-1MP_P1.00mm_Horizontal
TP1, TP2: TestPoint; TestPoint_Pad_D4.0mm
U1: VEML6030; SENSORS-SMD_VEML6030; MPN VEML6030; LCSC Part C132182
U2, U3: TTP223-BA6-TD; SOT-23-6_L2.9-W1.6-P0.95-LS2.9-BL; LCSC Part C42422127

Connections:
+3V3: C1.1, C3.1, C5.1, J1.2, J2.4, U1.6 (VDD), U2.5 (VDD), U3.5 (VDD)
/INT: J2.7, U1.3 (INT)
/S1: J2.1, U2.1 (OUT)
/S2: J2.2, U3.1 (OUT)
/SCL: J1.3, J2.6, U1.5 (SCL)
/SDA: J1.4, J2.5, U1.2 (SDA)
/SO1: C2.1, TP1.1, U2.3 (SO)
/SO2: C4.1, TP2.1, U3.3 (SO)
GND: C1.2, C2.2, C3.2, C4.2, C5.2, J1.1, J2.3, U1.1 (GND), U2.2 (GND), U2.4 (SLH), U2.6 (STG), U3.2 (GND), U3.4 (SLH), U3.6 (STG)

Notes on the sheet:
touch sensors
I2C devices
board connector

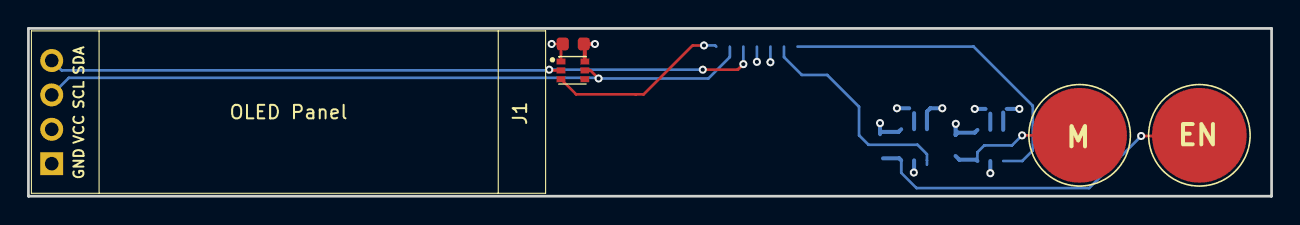
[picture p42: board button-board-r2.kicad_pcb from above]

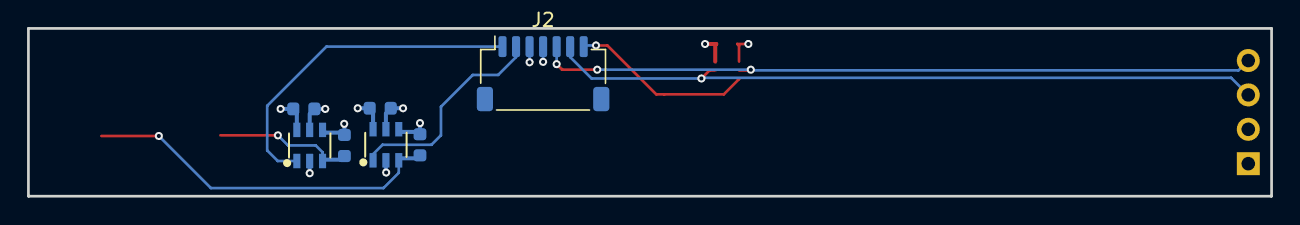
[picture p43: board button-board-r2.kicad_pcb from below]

Board: 4 copper layers, 91.9 x 12.4 mm, 12 parts (7 on the bottom side), 9 nets.

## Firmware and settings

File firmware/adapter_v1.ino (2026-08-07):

/*******************************************************************************
 * Sensors:
 *   - ENS210      temperature + humidity   (I2C 0x43)
 *   - BMP580      pressure + temperature    (I2C 0x47, default)
 *   - RX8900      real-time clock           (I2C 0x32, default)
 *   - LIS2DW12    3-axis accelerometer      (SPI, CS on IO18)
 *   - SCD41       CO2 / T / RH              (I2C 0x62)
 *                 pressure comp. from BMP580, temperature offset ref from ENS210
 *   - 4x HT16K33A 8x8 bicolour matrices     (I2C 0x70..0x73, drawn as one 32x8)
 *
 * Display modes (cycled with S2):
 *   0 = clock
 *   1 = fire
 *   2 = particles
 *
 ******************************************************************************/

#include <Wire.h>
#include <SPI.h>

#include <Adafruit_GFX.h>
#include "Adafruit_LEDBackpack.h"

#include <SparkFun_BMP581_Arduino_Library.h>
#include "SparkFun_SCD4x_Arduino_Library.h"
#include "ens210.h"
#include <TimeLib.h>
#include <RX8900RTC.h>
#include <LIS2DW12Sensor.h>

using namespace ScioSense;

// ---------------------------------------------------------------------------
// Pin definitions
// ---------------------------------------------------------------------------
static const int PIN_SDA     = 3;
static const int PIN_SCL     = 19;
static const int PIN_SCK     = 5;
static const int PIN_MISO    = 6;
static const int PIN_MOSI    = 7;
static const int PIN_CS_ACC  = 18;
static const int PIN_INT1    = 4;   // LIS2DW12 interrupt (unused for now)
static const int PIN_BTN_S1  = 0;   // brightness
static const int PIN_BTN_S2  = 1;   // mode

// ---------------------------------------------------------------------------
// I2C addresses
// ---------------------------------------------------------------------------
static const uint8_t MATRIX_ADDR[4] = { 0x70, 0x71, 0x72, 0x73 };

// ---------------------------------------------------------------------------
// Objects
// ---------------------------------------------------------------------------
Adafruit_BicolorMatrix matrix[4] = {
  Adafruit_BicolorMatrix(), Adafruit_BicolorMatrix(),
  Adafruit_BicolorMatrix(), Adafruit_BicolorMatrix()
};

BMP581           bmp;            // BMP580/BMP581
SCD4x            scd(SCD4x_SENSOR_SCD41);
ENS210           ens210;
RX8900RTC        rtc;
LIS2DW12Sensor   accel(&SPI, PIN_CS_ACC);

// ---------------------------------------------------------------------------
// Shared sensor state
// ---------------------------------------------------------------------------
struct SensorData {
  float ensTempC   = NAN;   // ENS210 ambient temperature
  float ensHum     = NAN;   // ENS210 relative humidity (%)
  float bmpTempC   = NAN;   // BMP580 die temperature
  float bmpPresPa  = NAN;   // BMP580 pressure (Pa)
  uint16_t co2     = 0;     // SCD41 CO2 (ppm)
  float scdTempC   = NAN;   // SCD41 temperature
  float scdHum     = NAN;   // SCD41 humidity (%)
  int32_t accel_mg[3] = {0, 0, 0};
  bool scdValid    = false;
} data;

// ---------------------------------------------------------------------------
// Display state
// ---------------------------------------------------------------------------
static const int CANVAS_W = 32;         // four 8x8 panels side by side
static const int CANVAS_H = 8;

enum Mode : uint8_t { MODE_CLOCK = 0, MODE_FIRE, MODE_PARTICLES, MODE_COUNT };
uint8_t mode = MODE_CLOCK;

uint16_t clockColour = LED_GREEN;
uint8_t  brightness  = 8;               // 0..15
bool     particlesReady = false;        // fluid sim re-seeds when false

// ---------------------------------------------------------------------------
// Timing
// ---------------------------------------------------------------------------
unsigned long lastSensorRead = 0;
unsigned long lastTempCal     = 0;
const unsigned long SENSOR_PERIOD_MS = 2000;
const unsigned long TEMP_CAL_MS      = 10UL * 60UL * 1000UL;   // 10 min

// ===========================================================================
// Setup
// ===========================================================================
void setup() {
  Serial.begin(115200);
  delay(200);
  Serial.println(F("\n[adapter] boot"));

  pinMode(PIN_BTN_S1, INPUT_PULLUP);
  pinMode(PIN_BTN_S2, INPUT_PULLUP);

  Wire.begin(PIN_SDA, PIN_SCL);
  Wire.setClock(400000);

  SPI.begin(PIN_SCK, PIN_MISO, PIN_MOSI, PIN_CS_ACC);

  initMatrices();
  initBMP();
  initENS210();
  initRTC();
  initAccel();
  initSCD();          // must run after BMP/ENS so we can seed compensation

  Serial.println(F("[adapter] init complete"));
}

// ===========================================================================
// Peripheral init helpers
// ===========================================================================
void initMatrices() {
  for (int i = 0; i < 4; i++) {
    matrix[i].begin(MATRIX_ADDR[i]);
    matrix[i].setRotation(0);          // adjust per physical orientation
    matrix[i].setBrightness(brightness);
    matrix[i].setTextWrap(false);
    matrix[i].setTextSize(1);
    matrix[i].clear();
    matrix[i].writeDisplay();
  }
  Serial.println(F("[matrix] 4x HT16K33 ready"));
}

void initBMP() {
  if (bmp.beginI2C(BMP581_I2C_ADDRESS_DEFAULT) != BMP5_OK) {
    Serial.println(F("[bmp] NOT found (0x47)"));
  } else {
    Serial.println(F("[bmp] ready"));
  }
}

void initENS210() {
  ens210.begin();
  Serial.println(F("[ens210] ready"));
}

void initRTC() {
  rtc.init();
  // Seed the RTC with the build time if it looks unset (before 2024).
  tmElements_t now = rtc.read();
  if (tmYearToCalendar(now.Year) < 2024) {
    time_t compiled = buildTime();
    if (compiled != 0) {
      rtc.set(compiled);
      Serial.println(F("[rtc] seeded with build time"));
    }
  }
  Serial.println(F("[rtc] ready"));
}

void initAccel() {
  if (accel.begin() != LIS2DW12_STATUS_OK) {
    Serial.println(F("[accel] begin failed"));
    return;
  }
  accel.Enable_X();
  Serial.println(F("[accel] ready"));
}

void initSCD() {
  // Do not auto-start measurement so we can program compensation first.
  if (scd.begin(false, true, false, true, Wire) == false) {
    Serial.println(F("[scd] NOT found (0x62)"));
    return;
  }
  scd.stopPeriodicMeasurement();       // ensure idle before configuring

  // Seed pressure compensation from BMP580 (falls back to sea level).
  bmp5_sensor_data bd = {0, 0};
  if (bmp.getSensorData(&bd) == BMP5_OK) {
    scd.setAmbientPressure(bd.pressure);        // Pascals
  } else {
    scd.setAmbientPressure(101325.0f);
  }

  // Initial self-heating temperature offset. Refined later against ENS210.
  scd.setTemperatureOffset(4.0f);

  scd.startPeriodicMeasurement();
  Serial.println(F("[scd] ready (periodic)"));
}

void loop() {
  handleButtons();

  unsigned long nowMs = millis();
  if (nowMs - lastSensorRead >= SENSOR_PERIOD_MS) {
    lastSensorRead = nowMs;
    readSensors();
    pushCompensation();
    logSensors();
  }

  if (nowMs - lastTempCal >= TEMP_CAL_MS) {
    lastTempCal = nowMs;
    recalibrateScdTempOffset();
  }

  // Render one animation frame for the active mode.
  renderMode();
}

// ===========================================================================
// Sensor acquisition
// ===========================================================================
void readSensors() {
  // ENS210 (blocking single-shot, ~130 ms)
  if (ens210.singleShotMeasure() == ENS210::Result::STATUS_OK) {
    data.ensTempC = ens210.getTempCelsius();
    data.ensHum   = ens210.getHumidityPercent();
  }

  // BMP580
  bmp5_sensor_data bd = {0, 0};
  if (bmp.getSensorData(&bd) == BMP5_OK) {
    data.bmpTempC  = bd.temperature;
    data.bmpPresPa = bd.pressure;
  }

  // SCD41 (fresh roughly every 5 s in periodic mode)
  if (scd.readMeasurement()) {
    data.co2      = scd.getCO2();
    data.scdTempC = scd.getTemperature();
    data.scdHum   = scd.getHumidity();
    data.scdValid = true;
  }

  // LIS2DW12
  accel.Get_X_Axes(data.accel_mg);
}

// Continuous pressure compensation for the SCD41 (allowed while measuring).
void pushCompensation() {
  if (!isnan(data.bmpPresPa) && data.bmpPresPa > 30000.0f) {
    scd.setAmbientPressure(data.bmpPresPa);
  }
}

// Periodically trim the SCD41 temperature offset so its reported temperature
// tracks the ENS210 ambient reading. Requires stopping periodic measurement.
void recalibrateScdTempOffset() {
  if (!data.scdValid || isnan(data.ensTempC) || isnan(data.scdTempC)) return;

  scd.stopPeriodicMeasurement();
  float current = scd.getTemperatureOffset();
  float delta   = data.scdTempC - data.ensTempC;   // how much hotter SCD reads
  float updated = current + delta;
  if (updated < 0)  updated = 0;
  if (updated > 20) updated = 20;
  scd.setTemperatureOffset(updated);
  scd.startPeriodicMeasurement();

  Serial.print(F("[scd] temp offset -> "));
  Serial.println(updated, 2);
}

// ===========================================================================
// Buttons
// ===========================================================================
void handleButtons() {
  static uint32_t lastS1 = 0, lastS2 = 0;
  uint32_t nowMs = millis();

  if (digitalRead(PIN_BTN_S1) == LOW && nowMs - lastS1 > 250) {
    lastS1 = nowMs;
    brightness = (brightness + 4) & 0x0F;   // step through 0,4,8,12
    for (int i = 0; i < 4; i++) matrix[i].setBrightness(brightness);
  }
  if (digitalRead(PIN_BTN_S2) == LOW && nowMs - lastS2 > 250) {
    lastS2 = nowMs;
    mode = (mode + 1) % MODE_COUNT;
    onModeChange();
  }
}

void onModeChange() {
  particlesReady = false;                // force re-seed of the fluid sim
  canvasClear();
  canvasShow();
  Serial.print(F("[mode] -> "));
  Serial.println(mode);
}

// ===========================================================================
// Canvas helpers: four 8x8 panels addressed as one 32x8 surface
// ===========================================================================
// Global x maps to panel (x / 8) at local column (x % 8). With rotation 0 the
// GFX drawPixel writes straight into that panel's row/column buffer.
inline void canvasClear() {
  for (int i = 0; i < 4; i++) matrix[i].clear();
}

inline void canvasShow() {
  for (int i = 0; i < 4; i++) matrix[i].writeDisplay();
}

inline void canvasPixel(int x, int y, uint16_t colour) {
  if (x < 0 || x >= CANVAS_W || y < 0 || y >= CANVAS_H) return;
  matrix[x >> 3].drawPixel(x & 7, y, colour);
}

void renderMode() {
  switch (mode) {
    case MODE_CLOCK:     renderClock();     break;
    case MODE_FIRE:      renderFire();      break;
    case MODE_PARTICLES: renderParticles(); break;
  }
}

// ---------------------------------------------------------------------------
// Mode 0: clock  (HH:MM centred on the 32x8 surface, colon blinks at 1 Hz)
// ---------------------------------------------------------------------------
void renderClock() {
  tmElements_t tm = rtc.read();
  bool colon = (millis() / 500) % 2;

  char buf[6];
  snprintf(buf, sizeof(buf), "%02d%c%02d",
           tm.Hour, colon ? ':' : ' ', tm.Minute);

  canvasClear();
  const int off = 1;                       // "HH:MM" = 30 px, 1 px left margin
  for (int i = 0; i < 4; i++) {
    matrix[i].setCursor(off - i * 8, 0);
    matrix[i].setTextColor(clockColour);
    matrix[i].print(buf);
  }
  canvasShow();
  delay(50);
}

// ---------------------------------------------------------------------------
// Mode 1: fire  (Doom-style upward propagation; hotter cells burn "orange")
// ---------------------------------------------------------------------------
uint8_t heat[CANVAS_H][CANVAS_W];

void renderFire() {
  // Seed the bottom row with fresh heat, flickering some cells low.
  for (int x = 0; x < CANVAS_W; x++) {
    heat[CANVAS_H - 1][x] = (random(100) < 80) ? 255 : (uint8_t)random(80, 160);
  }

  // Propagate heat upward with cooling and a little horizontal blur.
  for (int y = 0; y < CANVAS_H - 1; y++) {
    for (int x = 0; x < CANVAS_W; x++) {
      int b  = heat[y + 1][x];
      int bl = heat[y + 1][max(0, x - 1)];
      int br = heat[y + 1][min(CANVAS_W - 1, x + 1)];
      int v  = (b * 2 + bl + br) / 4 - (int)random(0, 42);
      heat[y][x] = v < 0 ? 0 : (uint8_t)v;
    }
  }

  canvasClear();
  for (int y = 0; y < CANVAS_H; y++) {
    for (int x = 0; x < CANVAS_W; x++) {
      uint8_t h = heat[y][x];
      if      (h >= 150) canvasPixel(x, y, LED_YELLOW);   // orange flame
      else if (h >=  55) canvasPixel(x, y, LED_RED);      // ember
      // else: cell stays off
    }
  }
  canvasShow();
  delay(55);
}

// ---------------------------------------------------------------------------
// Mode 2: particles  (gravity vector taken from the LIS2DW12 accelerometer)
// ---------------------------------------------------------------------------
static const int   NUM_PARTICLES = 26;
static const float GRAV        = 0.16f;   // gravity strength (tune to taste)
static const float DAMP        = 0.90f;   // velocity damping per frame
static const float RESTITUTION = 0.35f;   // wall bounciness
// Flip these to match the physical mounting of the accelerometer.
static const float ACC_X_SIGN = -1.0f;
static const float ACC_Y_SIGN =  1.0f;

float px[NUM_PARTICLES], py[NUM_PARTICLES];
float vx[NUM_PARTICLES], vy[NUM_PARTICLES];

void seedParticles() {
  for (int i = 0; i < NUM_PARTICLES; i++) {
    px[i] = random(0, CANVAS_W * 100) / 100.0f;
    py[i] = random(0, CANVAS_H * 100) / 100.0f;
    vx[i] = vy[i] = 0.0f;
  }
  particlesReady = true;
}

void renderParticles() {
  if (!particlesReady) seedParticles();

  // Live gravity direction from the accelerometer (values in mg -> g).
  int32_t a[3];
  accel.Get_X_Axes(a);
  float gx = ACC_X_SIGN * (a[0] / 1000.0f) * GRAV;
  float gy = ACC_Y_SIGN * (a[1] / 1000.0f) * GRAV;

  for (int i = 0; i < NUM_PARTICLES; i++) {
    vx[i] = (vx[i] + gx) * DAMP;
    vy[i] = (vy[i] + gy) * DAMP;
    px[i] += vx[i];
    py[i] += vy[i];

    if (px[i] < 0)              { px[i] = 0;              vx[i] = -vx[i] * RESTITUTION; }
    if (px[i] > CANVAS_W - 1)   { px[i] = CANVAS_W - 1;   vx[i] = -vx[i] * RESTITUTION; }
    if (py[i] < 0)              { py[i] = 0;              vy[i] = -vy[i] * RESTITUTION; }
    if (py[i] > CANVAS_H - 1)   { py[i] = CANVAS_H - 1;   vy[i] = -vy[i] * RESTITUTION; }
  }

  canvasClear();
  for (int i = 0; i < NUM_PARTICLES; i++) {
    canvasPixel((int)(px[i] + 0.5f), (int)(py[i] + 0.5f), LED_GREEN);
  }
  canvasShow();
  delay(30);
}

// ---------------------------------------------------------------------------
// Helper: current time as HH:MM:SS (used for serial logging)
// ---------------------------------------------------------------------------
String timeString() {
  tmElements_t tm = rtc.read();
  char buf[9];
  snprintf(buf, sizeof(buf), "%02d:%02d:%02d", tm.Hour, tm.Minute, tm.Second);
  return String(buf);
}

// ===========================================================================
// Serial logging
// ===========================================================================
void logSensors() {
  Serial.print(F("[data] "));
  Serial.print(timeString());
  Serial.print(F("  ENS T="));  Serial.print(data.ensTempC, 2);
  Serial.print(F("C RH="));     Serial.print(data.ensHum, 1);
  Serial.print(F("%  BMP P=")); Serial.print(data.bmpPresPa / 100.0f, 1);
  Serial.print(F("hPa T="));    Serial.print(data.bmpTempC, 2);
  Serial.print(F("C  SCD CO2="));Serial.print(data.co2);
  Serial.print(F("ppm T="));    Serial.print(data.scdTempC, 2);
  Serial.print(F("C RH="));     Serial.print(data.scdHum, 1);
  Serial.print(F("%  ACC[mg]=")); Serial.print(data.accel_mg[0]);
  Serial.print(',');            Serial.print(data.accel_mg[1]);
  Serial.print(',');            Serial.println(data.accel_mg[2]);
}

// ===========================================================================
// Build-time -> time_t (used to seed the RTC on a fresh board)
// ===========================================================================
time_t buildTime() {
  const char *monthNames = "JanFebMarAprMayJunJulAugSepOctNovDec";
  char monStr[4];
  int day, year, hour, minute, second;

  if (sscanf(__DATE__, "%3s %d %d", monStr, &day, &year) != 3) return 0;
  if (sscanf(__TIME__, "%d:%d:%d", &hour, &minute, &second) != 3) return 0;

  int month = (strstr(monthNames, monStr) - monthNames) / 3 + 1;

  tmElements_t tm;
  tm.Year   = CalendarYrToTm(year);
  tm.Month  = month;
  tm.Day    = day;
  tm.Hour   = hour;
  tm.Minute = minute;
  tm.Second = second;
  return makeTime(tm);
}

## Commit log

2026-08-07 feat: all changes
    [adapter-board-r2.kicad_pcb, adapter-board-r2.kicad_sch, bicolour-matrix.kicad_pcb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]
2026-08-19 feat: updated pcb
    [adapter-board-r2.kicad_pcb, adapter-board-r2.kicad_sch]
2026-08-21 feat: adapter, button changes
    [adapter-board-r2.kicad_pcb, adapter-board-r2.kicad_sch, bom.csv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]
2026-08-21 rm: v1 files
    [adapter-board.kicad_pcb, adapter-board.kicad_sch, bom.csv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]
2026-08-21 feat: rounded edges
    [adapter-board-r2.kicad_pcb, bicolour-matrix.kicad_pcb]
2026-08-30 feat: final update
    [adapter-board-r2.kicad_pcb, bicolour-matrix.kicad_pcb, designators.csv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]
2026-09-06 feat: added simple enclosure
    [Enclosure-r2.stl]
2026-09-09 feat: better power connections
    [bicolour-matrix.kicad_pcb]
